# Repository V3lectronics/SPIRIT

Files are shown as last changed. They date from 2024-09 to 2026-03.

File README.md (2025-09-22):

<p align="center">
    
</p>





Open source smartphone, from available components. Prioritizing user experience, performance, control, repairability, innovation and privacy.
Contribution and feedback are very welcome! **[Contribution Guide](https://github.com/V3lectronics/SPIRIT/blob/main/CONTRIBUTING.md)**.

We are currently in the development phase, progress is documented here and on the V Electronics **[YT channel](https://www.youtube.com/@V_Electronics)**. For information about the project please refer to the **[SPIRIT wiki](https://github.com/V3lectronics/SPIRIT/wiki)**.

> [!IMPORTANT]  
> Watch out for fake websites and repositories!
> 
> Before making suggestions and opening new discussions, search the **[issue list](https://github.com/V3lectronics/SPIRIT/issues)**!

# Quick links
1. **[Technical specifications](https://github.com/V3lectronics/SPIRIT/wiki/Overview-technical-specs)**
2. **[Hardware and electronics](https://github.com/V3lectronics/SPIRIT/wiki/Hardware-and-electronics)**
3. **[Software and operating System](https://github.com/V3lectronics/SPIRIT/wiki/Operating-system)**
4. **[SPIRIT wiki](https://github.com/V3lectronics/SPIRIT/wiki)**
5. **[Community](https://github.com/V3lectronics/SPIRIT/wiki/Community)**
6. **[Contribution guide](https://github.com/V3lectronics/SPIRIT/blob/main/CONTRIBUTING.md)**
7. **[Parts list](https://github.com/V3lectronics/SPIRIT/wiki/Parts-list)** _Coming soon!!!_
8. **[Cost](https://github.com/V3lectronics/SPIRIT/wiki/Cost)** _Coming soon!!!_
9. **[Ethical and environmental concerns](https://github.com/V3lectronics/SPIRIT/wiki/Ethical-and-environmental-concerns)**
10. **[Compliance and legality](https://github.com/V3lectronics/SPIRIT/wiki/Compliance-and-legality)**
11. **[DIY build guide](https://github.com/V3lectronics/SPIRIT/wiki/DIY-build-guide)** _Coming soon!!!_
12. **[Resources](https://github.com/barbarjan/SPIRIT#resources)**

# Roadmap

### **Chassis**  
[Public Onshape project](https://cad.onshape.com/documents/4e52c2512b67af09635f94b3/w/56ef775ef64c6c9cfce93a1f/e/4e6df7991d5269c6c76f6984) → Onshape 3D model *(in progress)* → 3D printable chassis → CNC chassis

### **Electronic systems**  
Select critical components → Footprints, symbols, 3D models → Power system *(in progress)* → Audio → GPS & GSM → LCD → Camera → Vibration & flashlight → Fingerprint scanner

### **Integration**
Integrate systems into one motherboard or modular setup.

### **OS**
Documented separately, see [OS article](https://github.com/V3lectronics/SPIRIT/wiki/Operating-system).

# Early screenshots
<small> (click to expand) </small>

<table>
  <tr>
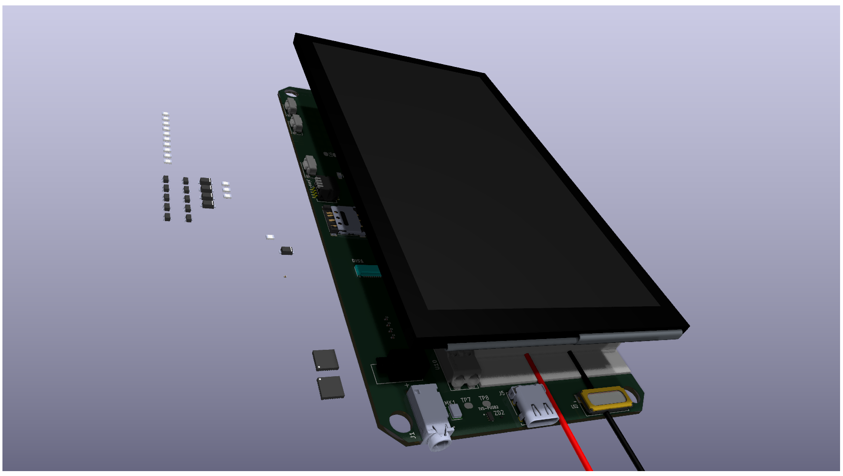
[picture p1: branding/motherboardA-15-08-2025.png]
motherboard PCB image
    <td></td>
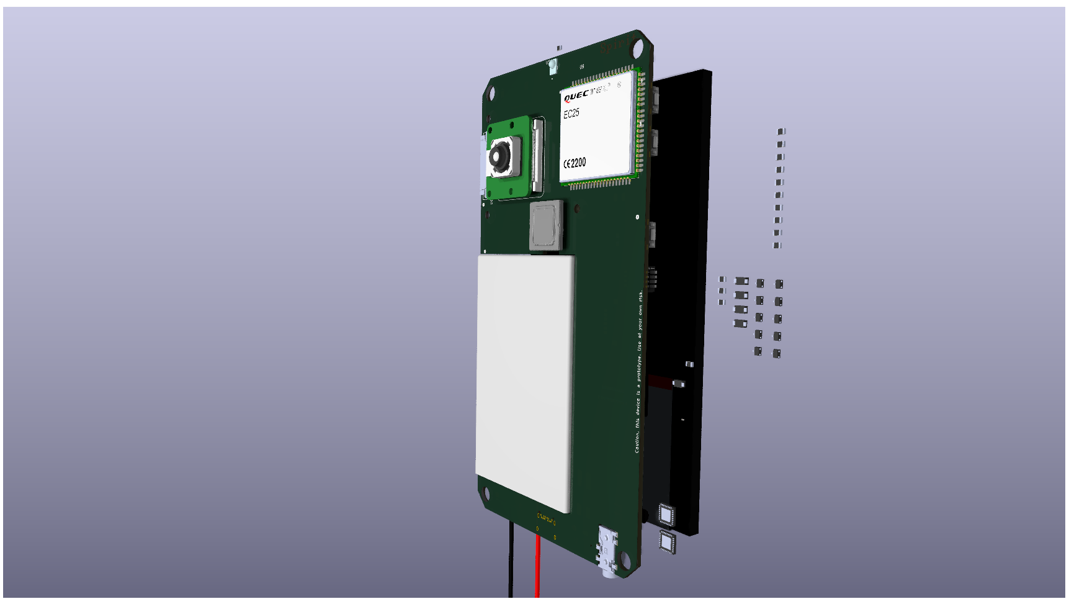
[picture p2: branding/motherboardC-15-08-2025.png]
motherboard PCB image
    <td></td>
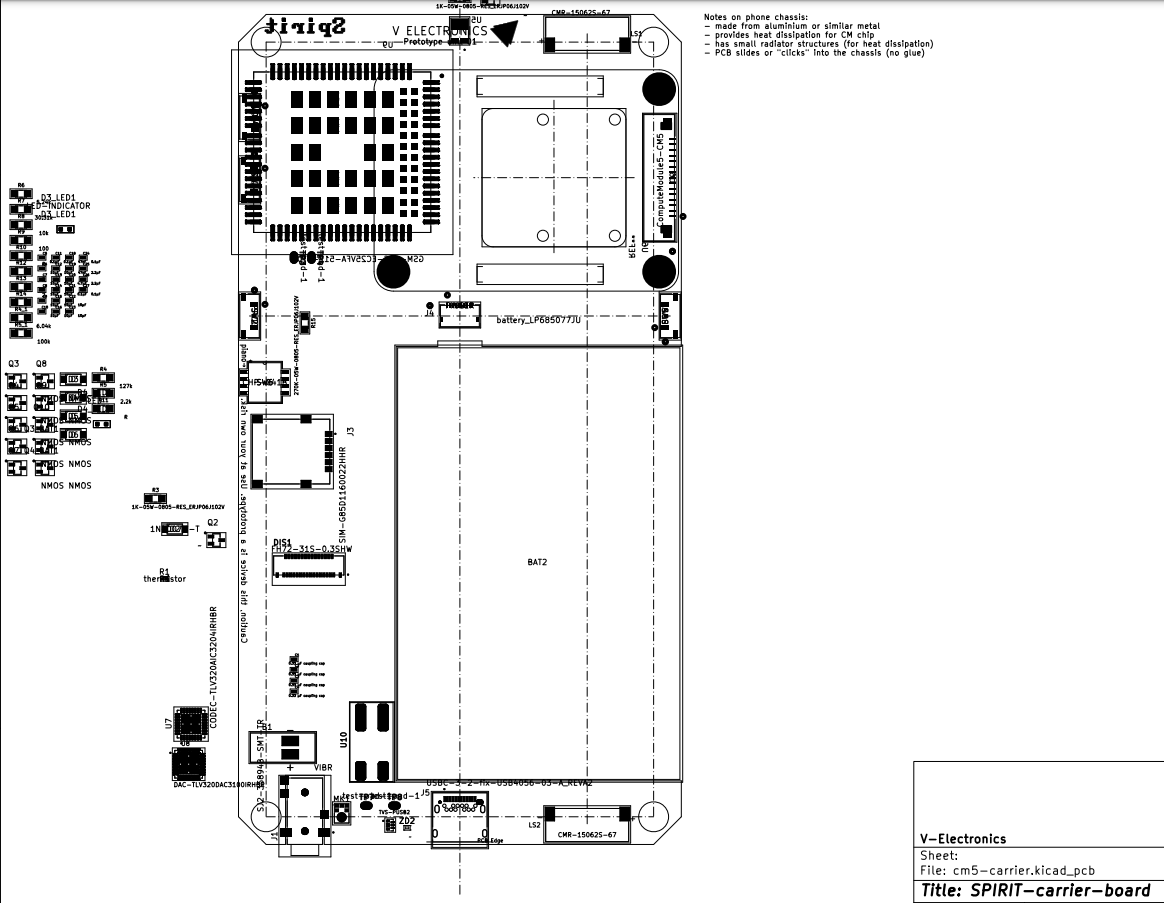
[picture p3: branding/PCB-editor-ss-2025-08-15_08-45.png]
    <td></td>
  </tr>
</table>

# Resources
- [SPIRIT wiki](https://github.com/V3lectronics/SPIRIT/wiki)
- [Rpi CM5 datasheet](https://datasheets.raspberrypi.com/cm5/cm5-datasheet.pdf)
- [Rpi CM4 datasheet](https://datasheets.raspberrypi.com/cm4/cm4-datasheet.pdf)
- [Rpi CM5 and CM 4 useful interactive pinout](https://atctwo.net/projects/pinout/index.html)

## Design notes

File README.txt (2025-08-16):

<p align="center">
    
</p>




Open source smartphone, from available components. Prioritizing user experience, performance, control, repairability, innovation and privacy.
Contribution and feedback are very welcome! [Contribution Guide](https://github.com/V3lectronics/SPIRIT/blob/main/CONTRIBUTING.md).

We are currently in the development phase, progress is documented here and on the V Electronics [YT channel](https://www.youtube.com/@V_Electronics). For information about the project please refer to the **[SPIRIT wiki](https://github.com/V3lectronics/SPIRIT/wiki)**.

# Quick links
1. **[Technical specifications](https://github.com/V3lectronics/SPIRIT/wiki/Overview-technical-specs)**
2. **[Hardware and electronics](https://github.com/V3lectronics/SPIRIT/wiki/Hardware-and-electronics)**
3. **[Software and operating System](https://github.com/V3lectronics/SPIRIT/wiki/Operating-system)**
4. **[SPIRIT wiki](https://github.com/V3lectronics/SPIRIT/wiki)**
5. **[Community](https://github.com/V3lectronics/SPIRIT/wiki/Community)**
6. **[Contribution guide](https://github.com/V3lectronics/SPIRIT/blob/main/CONTRIBUTING.md)**
7. **[Parts list](https://github.com/V3lectronics/SPIRIT/wiki/Parts-list)**
8. **[Cost](https://github.com/V3lectronics/SPIRIT/wiki/Cost)**
9. **[Ethical and environmental concerns](https://github.com/V3lectronics/SPIRIT/wiki/Ethical-and-environmental-concerns)**
10. **[Compliance and legality](https://github.com/V3lectronics/SPIRIT/wiki/Compliance-and-legality)**
11. **[DIY build guide](https://github.com/V3lectronics/SPIRIT/wiki/DIY-build-guide)** _Coming soon!!!_
12. **[Resources](https://github.com/barbarjan/SPIRIT#resources)**

# Progress



# Early screenshots
<small> (click to expand) </small>

<table>
  <tr>
    <td>motherboard PCB image</td>
    <td>motherboard PCB image</td>
    <td>motherboard PCB image</td>
  </tr>
</table>

# Resources
- [SPIRIT wiki](https://github.com/V3lectronics/SPIRIT/wiki)
- [Rpi CM5 datasheet](https://datasheets.raspberrypi.com/cm5/cm5-datasheet.pdf)
- [Rpi CM4 datasheet](https://datasheets.raspberrypi.com/cm4/cm4-datasheet.pdf)
- [Rpi CM5 and CM 4 useful interactive pinout](https://atctwo.net/projects/pinout/index.html)

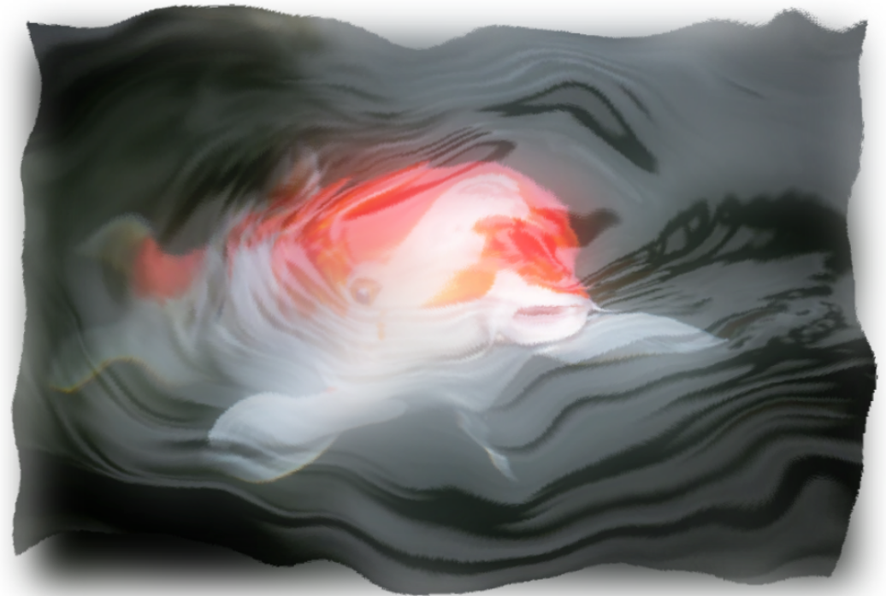
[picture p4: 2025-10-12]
branding/victoria-fish.png

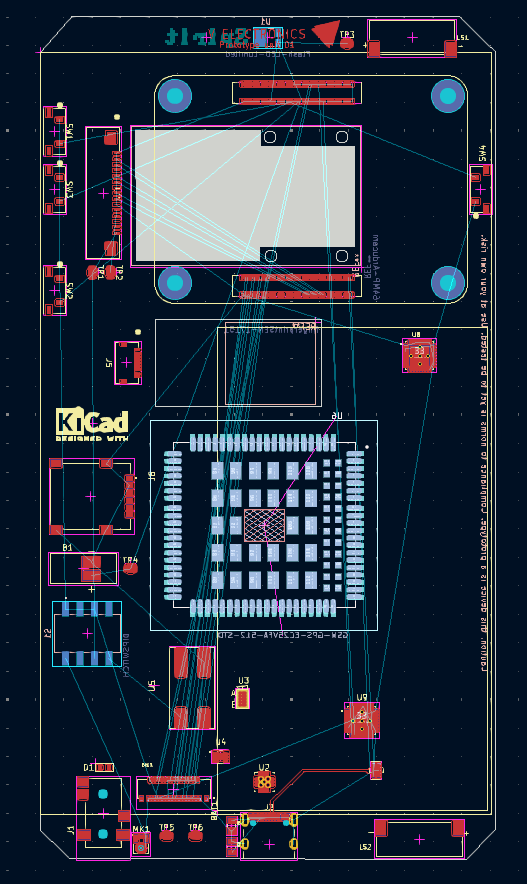
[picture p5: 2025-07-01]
branding/pcblayout26-12-2024.png

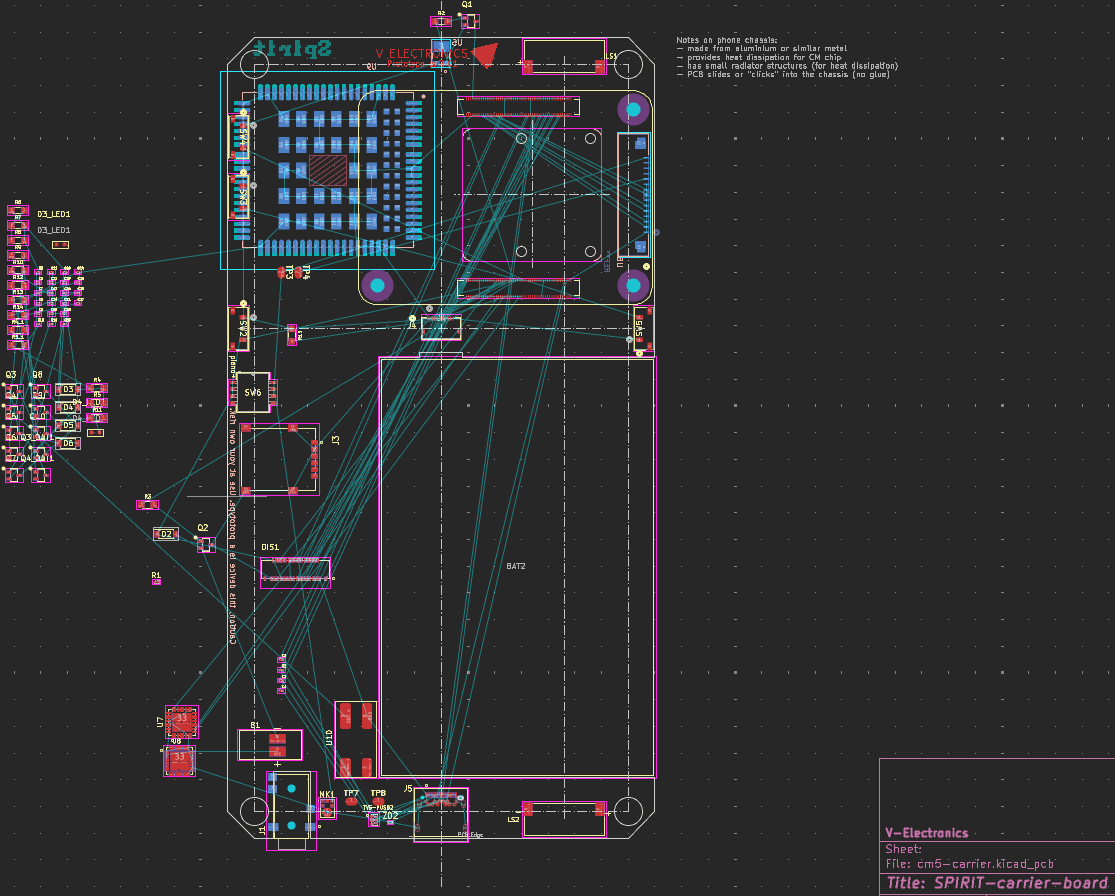
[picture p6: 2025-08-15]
branding/PCB-editor-ss-2025-08-15_08-57.png

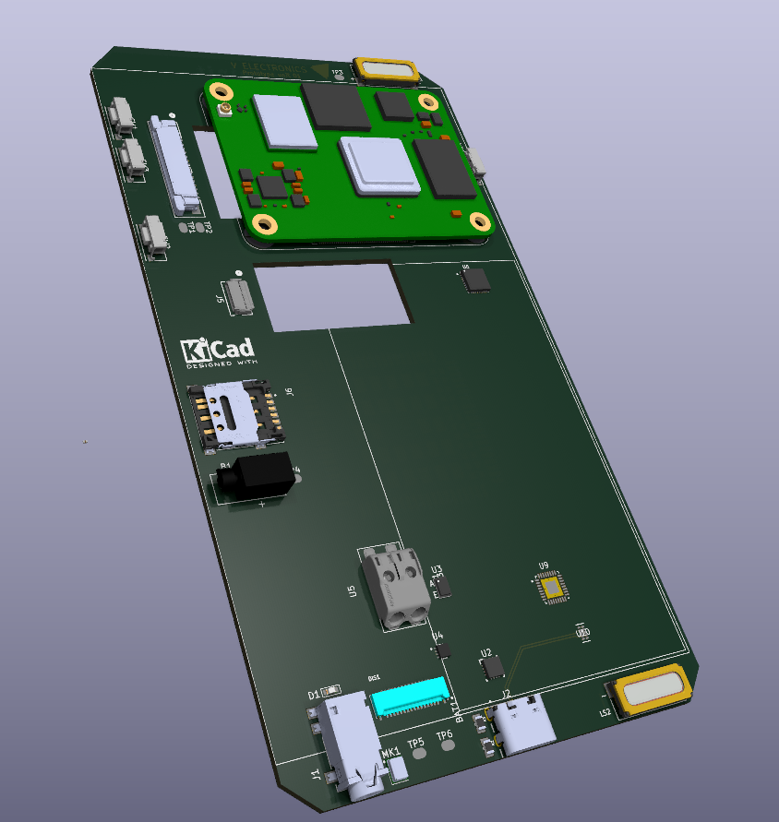
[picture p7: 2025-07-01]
branding/alt3view26-12-2024.png

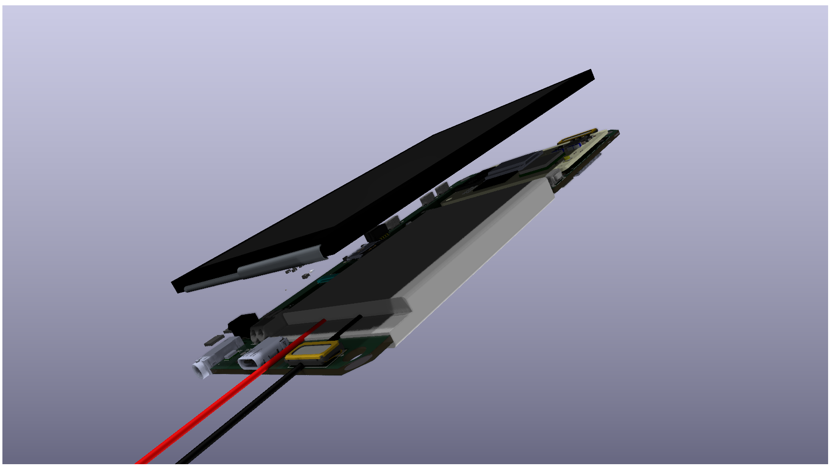
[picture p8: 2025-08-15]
branding/motherboardB-15-08-2025.png

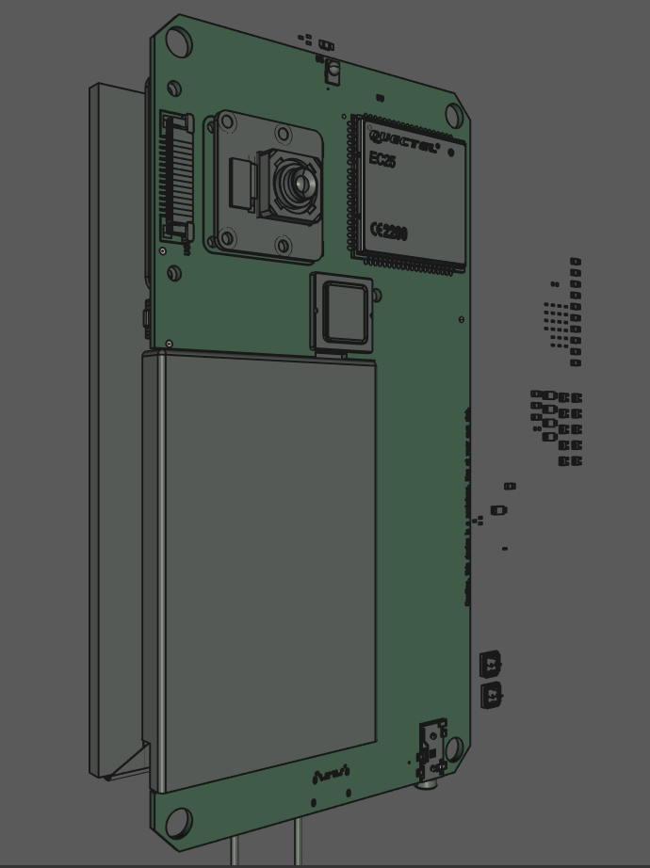
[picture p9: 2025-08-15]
branding/Freecad-ss-2025-08-15_09-00.png

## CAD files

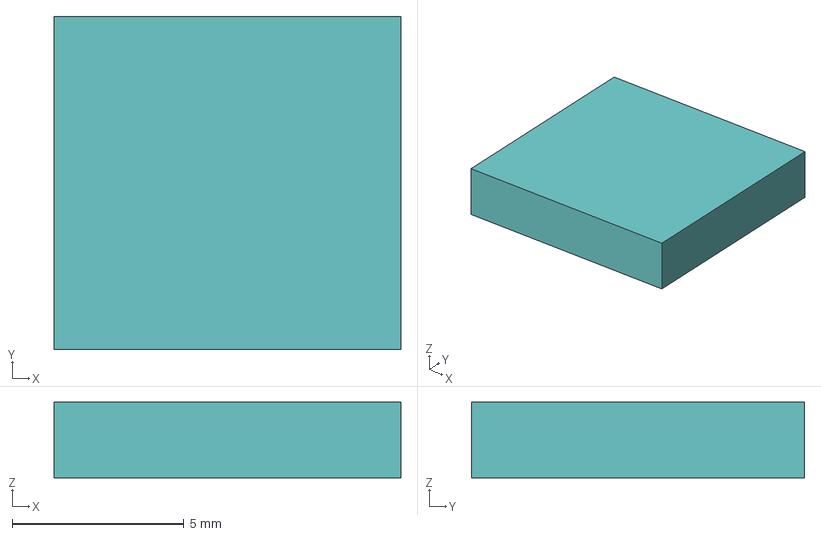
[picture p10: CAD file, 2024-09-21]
EDA-kicad/component-libs/SPIRIT-3D-models/FreeCAD-models/GPS-MODULE-YIC31009EBGG.FCStd
10.1 x 9.70 x 2.20 mm

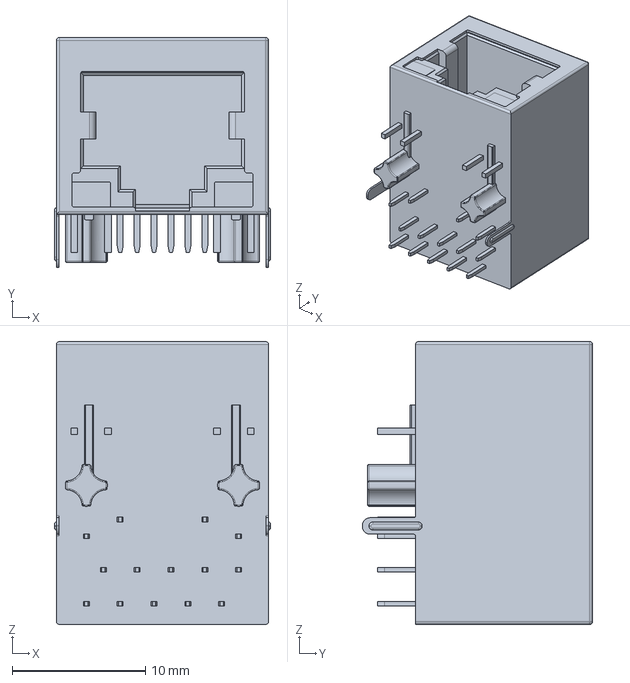
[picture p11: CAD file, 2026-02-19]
EDA-kicad/component-libs/SPIRIT-3D-models/TRJG0926HENL.stp
16.2 x 17.3 x 21.2 mm

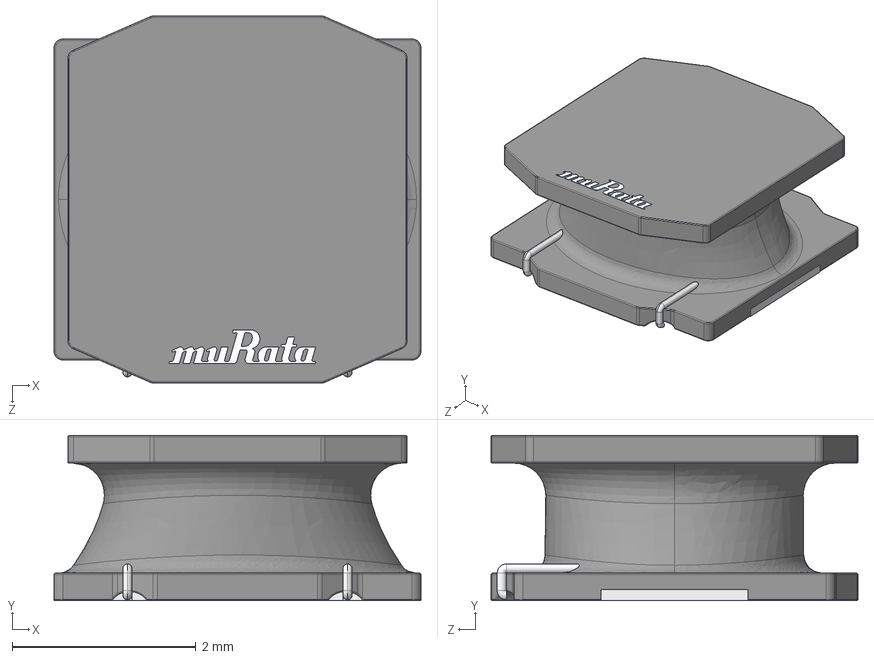
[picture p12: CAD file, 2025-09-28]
EDA-kicad/component-libs/SPIRIT-symbol-libs/3-3uH-LQH44PN3R3MPRL.step
4.00 x 1.80 x 4.00 mm
logo
terminals
terminal wire

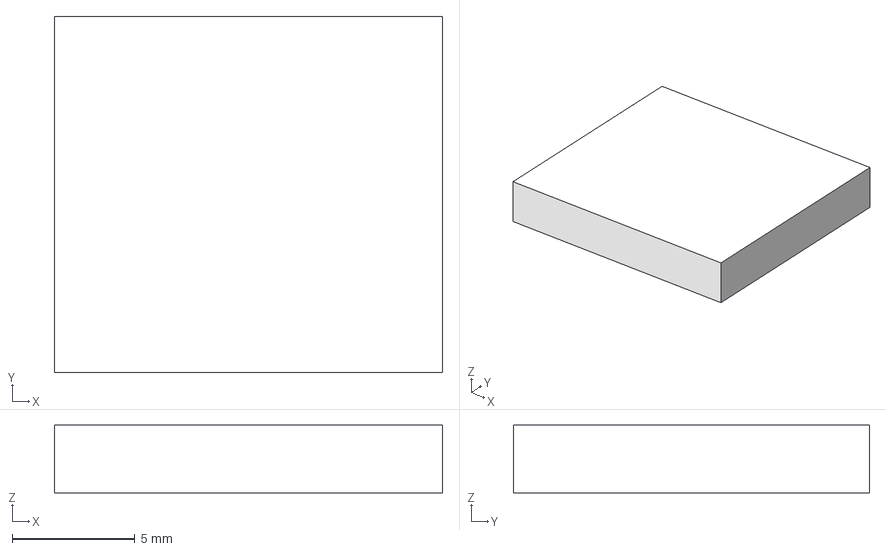
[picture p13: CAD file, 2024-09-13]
EDA-kicad/component-libs/SPIRIT-3D-models/FreeCAD-models/fingerprintSEN-17151.FCStd
15.8 x 14.5 x 2.75 mm

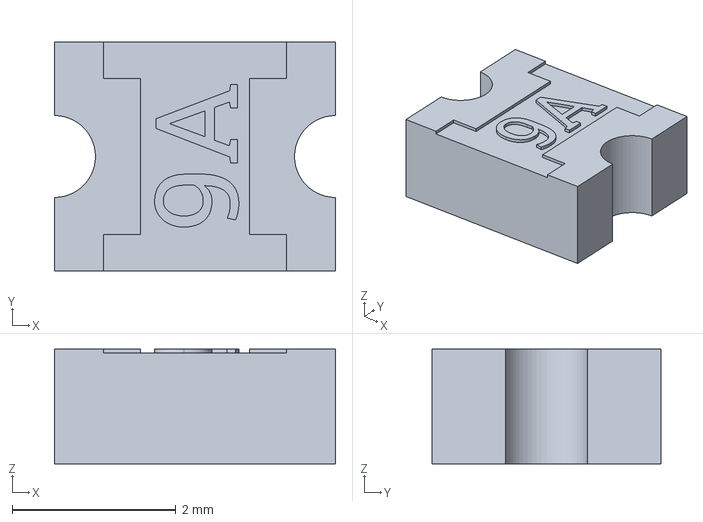
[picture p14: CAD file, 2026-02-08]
EDA-kicad/component-libs/SPIRIT-3D-models/reset-fuse-1210L900SLPR-Part.step
3.43 x 2.80 x 1.40 mm

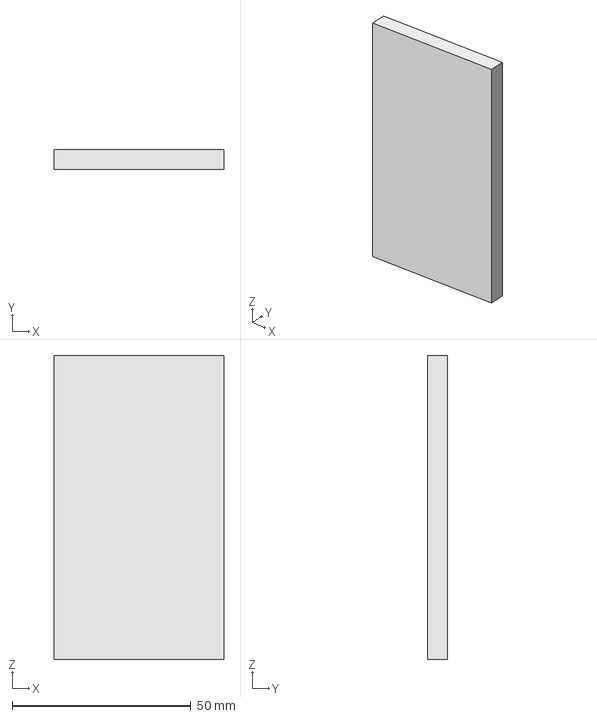
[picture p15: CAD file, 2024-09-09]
EDA-kicad/component-libs/SPIRIT-3D-models/FreeCAD-models/battery-37V2AhLP504783JU.FCStd
47.5 x 5.60 x 85.0 mm

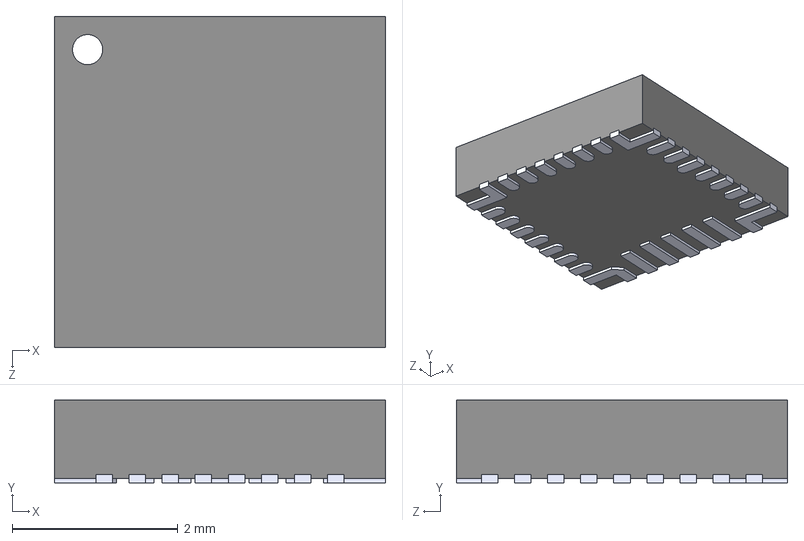
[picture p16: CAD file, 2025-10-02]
EDA-kicad/component-libs/SPIRIT-3D-models/charger-BQ25792RQMR.step
4.00 x 1.00 x 4.00 mm

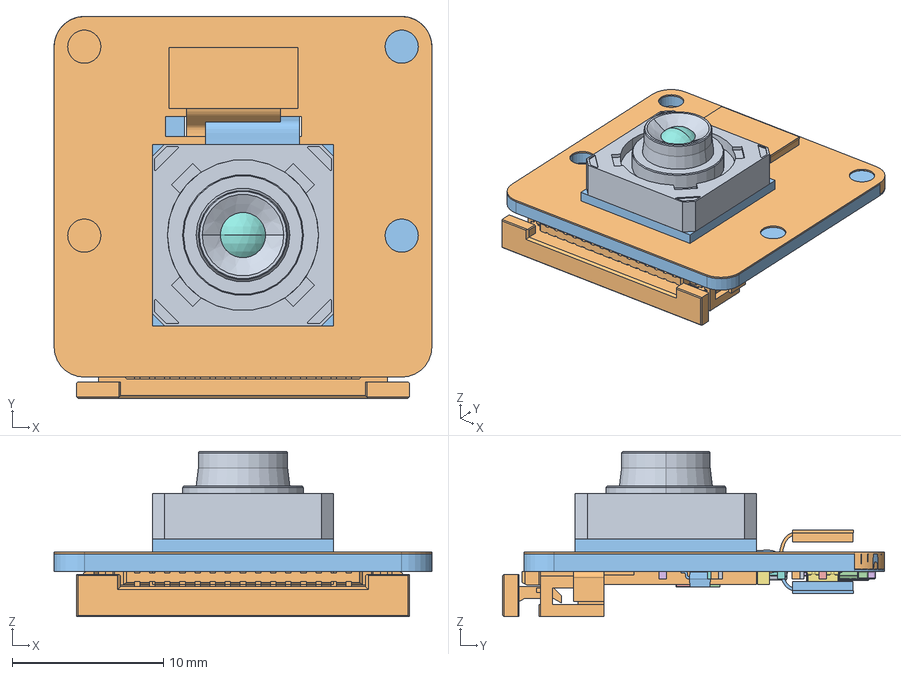
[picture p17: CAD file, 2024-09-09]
EDA-kicad/component-libs/SPIRIT-3D-models/FreeCAD-models/64MP-Arducam-colorless.FCStd
25.0 x 25.3 x 10.9 mm
B0399
B0400
B0401
B0402
B0403
B0404
B0405
B0406
B0407
B0408
B0409
B0410
B0411
B0412
B0413
B0414
B0415
B0416
B0417
B0418
B0419
B0420
B0421
B0422
B0423
B0424
B0425
B0426
B0427
B0428
B0429
B0430
B0431
B0432
B0433
B0434
B0435
B0436
B0437
B0438
B0439
B0440
B0441
B0442
B0443
B0444
B0445
B0446
B0447
B0448
B0449
B0450
B0451
B0452
B0453
B0454
B0455
B0456
B0457
B0458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

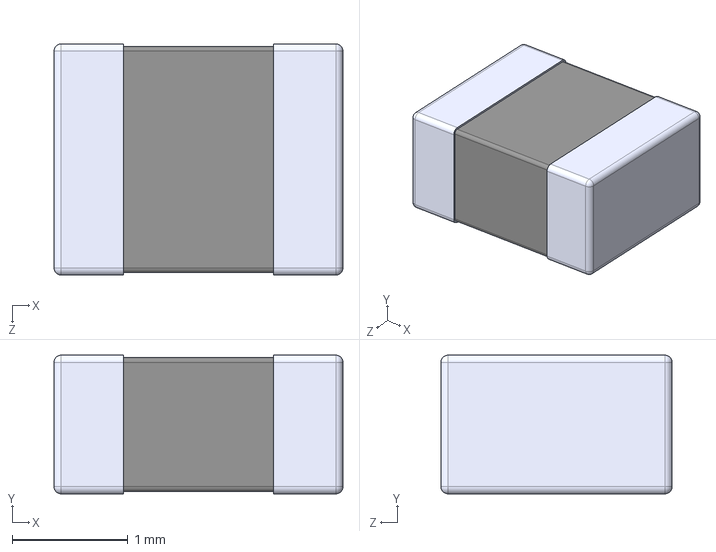
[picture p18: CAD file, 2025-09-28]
EDA-kicad/component-libs/SPIRIT-3D-models/2-2uH-inductor-DFE252012P-2R2M_P2.step
2.50 x 1.20 x 2.00 mm

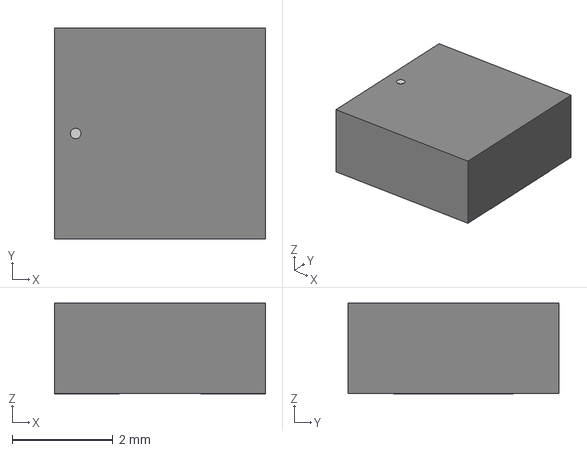
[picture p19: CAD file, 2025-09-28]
EDA-kicad/component-libs/SPIRIT-3D-models/6-8uH-inductor-LQH44PN6R8MPRLIND_LQH44PN_PR_MUR.step
4.19 x 4.19 x 1.81 mm

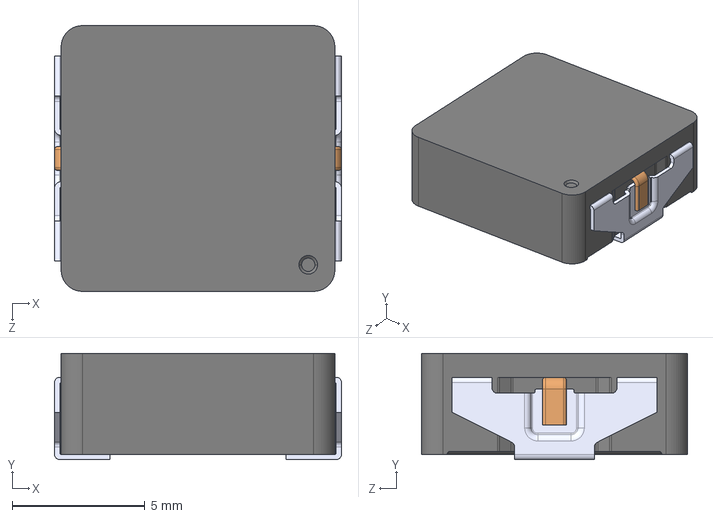
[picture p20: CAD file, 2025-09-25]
EDA-kicad/component-libs/SPIRIT-3D-models/2-2uh-inductorETQP4M2R2KVC.step
10.8 x 4.00 x 10.0 mm

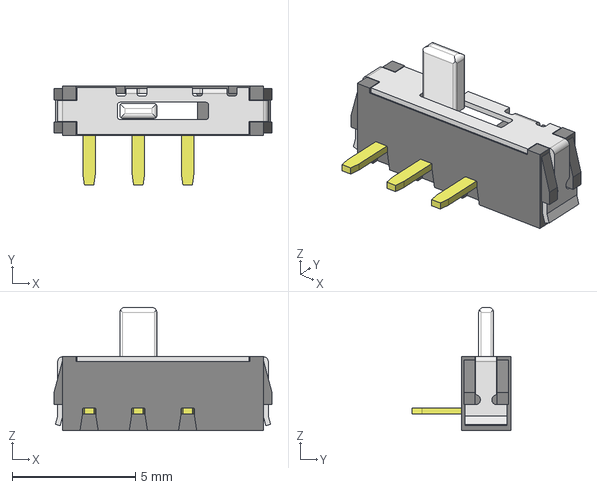
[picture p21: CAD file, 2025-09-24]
EDA-kicad/component-libs/SPIRIT-3D-models/privacy-switch-CSS-1210MC.stp
8.85 x 4.00 x 5.00 mm
CSS-1210MC-b
CSS-1210MC-s

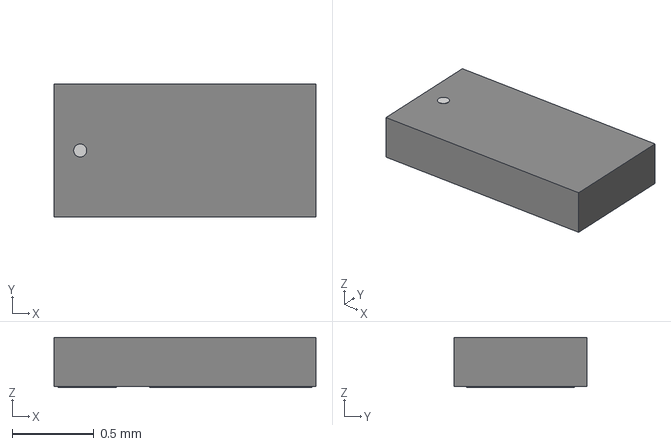
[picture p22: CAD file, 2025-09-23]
EDA-kicad/component-libs/SPIRIT-3D-models/0603-schottky-CR_DSN2_152AB-C_OSI.step
1.60 x 0.812 x 0.307 mm

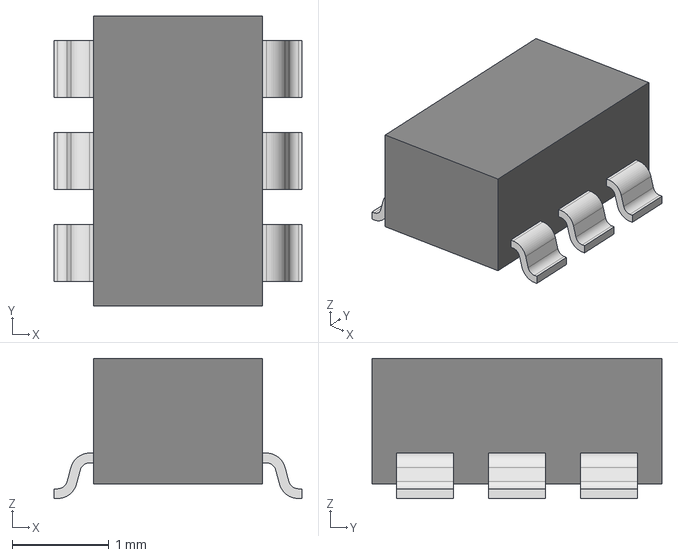
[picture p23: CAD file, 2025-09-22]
EDA-kicad/component-libs/SPIRIT-3D-models/SOT23-6_DIO.step
2.56 x 3.00 x 1.45 mm

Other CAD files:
EDA-kicad/component-libs/SPIRIT-3D-models/CC0805MKX5R5BB476-capacitor.STEP
EDA-kicad/component-libs/SPIRIT-3D-models/MP3429GL.step
EDA-kicad/component-libs/SPIRIT-3D-models/BSC0902NSIATMA1-PG-TDSON-8-6.step
EDA-kicad/component-libs/SPIRIT-3D-models/0603-capacitor.step
EDA-kicad/component-libs/SPIRIT-3D-models/0603-resistor.step
EDA-kicad/component-libs/SPIRIT-3D-models/10-FPC-unused.stp
EDA-kicad/component-libs/SPIRIT-3D-models/10-FPC.stp
EDA-kicad/component-libs/SPIRIT-3D-models/100K-0805-resistor-ERA6AEB104V.step
EDA-kicad/component-libs/SPIRIT-3D-models/1K-05W-0805-RES_ERJP06J102V.step
EDA-kicad/component-libs/SPIRIT-3D-models/35mmJACK-Same_Sky_SJ2-35894B-SMT-TR.step
EDA-kicad/component-libs/SPIRIT-3D-models/5-1KOhm-SMD-1perc-0125W-RTE0016C_NV.step
EDA-kicad/component-libs/SPIRIT-3D-models/Arducam16MPCamera.STEP
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

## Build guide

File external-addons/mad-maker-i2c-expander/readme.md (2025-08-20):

to do: provide an explanation and instructions on how to use this addon

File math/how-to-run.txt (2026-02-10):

The calculations are carried out in Octave, a free and open source program often described as a Matlab alternative. It is possible to run them in Matlab as well because the synthax is mostly compatible.

Octave website:
https://octave.org/

Octave download:
https://octave.org/download

TERMINAL
To run a file for example "test.m", simply execute the command:

$ octave test.m

This should start executing commands from the file line by line.

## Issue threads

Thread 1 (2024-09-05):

Can't add micro HDMI for debugging purposes (in case USB doesn't work)

V3lectronics, 2024-09-05:

Closed 2024-09-07.

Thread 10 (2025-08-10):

Add battery 3D .step model

V3lectronics, 2025-08-10:
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

datasheet with dimensions:
https://www.jauch.com/downloadfile/649e9f79226030849a0f5aea667759677/matd_251919_20230626_lp685077jupcm2_wires_70mm.pdf

MavLeague, 2025-08-12:
I could quickly make a model, if no one is already at it. But the dimensions are pretty plain, so except the main dimensions, I think I have to guess with like the wire placement.

boelle, 2025-08-13:
i think we can close this one as the model has been added
@V3lectronics

Closed 2025-08-13.

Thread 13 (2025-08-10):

Chassis: CAD Model, technical Drawings, Manufacturing Formats

MavLeague, 2025-08-10:
Todo:
- [ ] CAD Model
- [ ] technical Drawings for Product Qualifications
- [ ] Tool paths etc. for CNC machining

CAD Software: Onshape
- Public Project
- Browser based
everyone can follow the design process and see where I'm at

boelle, 2025-08-10:
Q: can others also edit or suggest edits ? i plan to invest in the hardware at some point if someone will help me get latest android working on it

my aim was to replace my old samsung with something i can fix myself if things break or wear out

MavLeague, 2025-08-10:
Yes, that's the plan. Onshape offers a version-history and is also made for collaboration with others. So I hope that it has the most benefit for this project. Also I am to be honest not really familiar with the workflow in fusion. I'm not sure if it offers the same benefits Onshape does.

boelle, 2025-08-10:
it does not have versio history, but you can give access to other people so they can work on the same model

a yes it does have some kind of version history in that each time you save the document gets a higher version number and you can revert to a version in the past if you F'up things

MavLeague, 2025-08-10:
Okay, but the workflow isn't like the cad workflow I am used to. Also I am not sure if public Projects are easily possible. So I think it's best to stick to Onshape for now.

But don't worry, suggestions are of course welcome!

MavLeague, 2025-08-13:
```mermaid
flowchart LR
    A[General 3D model<br/>based on PCB] --> B[Derive]

    B --> C[Optimize for 3D printing]
    C --> D[Slice]

    B --> E[Optimize for CNC Milling]
    E --> F[Technical Drawing]
    F --> G[Write CNC machining program]

MavLeague, 2025-08-13:
I've created a little Roadmap to show what my Plan is:

```mermaid
flowchart LR
    A[General 3D model<br/>based on PCB] --> B[Derive]

    B --> C[Optimize for 3D printing]
    C --> D[Slice]

    B --> E[Optimize for CNC Milling]
    E --> F[Technical Drawing]
    E --> G[Write CNC machining program]

MavLeague, 2025-08-16:
> Can anyone contribute to this?
>

It's a bit more complicated, but my goal is to explain that in the wiki. In a nutshell, we don't use GitHub but Onshape for creating the chassis so we have to approach it differently.

V3lectronics, 2025-08-20:
cm5 has been put to the back for better thermals:

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

koishi-514-shutdown, 2025-08-21:
希望外壳的摄像头不要占用背板大量面积，就像以前的手机一样简洁像iPhone6一样，并且可以在桌面上放平。
关于cm5的散热问题，我觉得可以在外壳相应位置提供类似铜或铝垫片来提供被动散热
希望可以有对应的3d打印手机壳模型
建议手机外壳设计的时候考虑电池的拆卸方便，设计一个结构可靠简单的外壳

V3lectronics, 2025-08-22:
button clearance fixed!

MavLeague, 2025-08-26:
There's now a wiki entry according to this issue.

This is a snippet of that:

## Designing Process

### CAD Software

You probably wonder where and how we create the model. We use Onshape as our CAD Program of choice because it makes collaboration really easy.

### View Progress

To see where we're at you can access the [Public Project at Onshape.](https://cad.onshape.com/documents/4e52c2512b67af09635f94b3/w/56ef775ef64c6c9cfce93a1f/e/4e6df7991d5269c6c76f6984)

To view it you **need** an Onshape Account (but the free plan is enough).

### Contribute
[_coming soon..._]

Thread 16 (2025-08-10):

Suggestion/idea... different sim card trays

boelle, 2025-08-10:
once we have a working prototype, why not have different sim card trays for the different sizes?

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

i would say skip the standard and concentrate on nano, micro and mini in that order

V3lectronics, 2025-08-15:
A simple adapter can be used, that's a standard solution:

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

boelle, 2025-08-15:
the tray just have to fit the largest one :-D

V3lectronics, 2025-08-15:
I'll close this for now

Closed 2025-08-15.

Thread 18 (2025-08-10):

GSM/GPS section (EC25 GSM/GPS, SIM holder)

V3lectronics, 2025-08-10:
We need someone to deal with the GSM/GPS schematic in KiCad

Main chip: https://www.digikey.pl/en/products/detail/quectel/EC25VFA-512-STD/13278151

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

BigBOSSJake, 2025-08-13:
Witch form factor do you like , I have a few Global options,and you want a phone network or just GPS?

BigBOSSJake, 2025-08-14:
The one that you have found is not vary global or easy to remove , a M.2 one is better for a lot of resons.

boelle, 2025-08-14:
hmm... would it not be the smartest to have wifi and gps seperate so you can update only one if say we get wifi 8 but that we still only have LTE 5G, no reason to update the GSM part then

V3lectronics, 2025-08-15:
Are we settling on eg25 as an upgrade to ec25? Maybe there are other suggestions?

BigBOSSJake, 2025-09-17:
Are we done ?

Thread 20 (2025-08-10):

POWER section (IN PROGRESS)

V3lectronics, 2025-08-10:
Help needed with implementing the power section schematic.

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

DansDesigns, 2025-08-29:
what are your main power requirements? are you running 5v into the CM? do you need 3v3 and 1v8 anywhere on the board?

I decided to use an off-the-shelf power converter that takes a native 1S lipo and converts it to 5v 3A, from there i am using 3v3 LDOs for local power where needed and to the CM for main 5v power...

V3lectronics, 2025-09-02:
Evaluation module from TI with the BQ25798:
https://www.ti.com/lit/ug/sluucb5e/sluucb5e.pdf?ts=1756794755662

Very useful, includes schematics and payout!!!

MrPouette, 2025-09-17:
We where looking to blink the R1202A regulator to modulate the Backlight brightness in the Youtube Live. But that would modulate the whole rail.
If it's only for the lcd, it seem to be a good solution to use less part but that would require to change the R1202A for a R1202D. Otherwise, we will modulate the output by the Output Capacitor Discharge Fet trough the CE pin(I think please take another look to the block diagram in datasheet).

Are we trying to conceive a 22V power rail for multiple part or only for the screen(RK055AHD091) ?

V3lectronics, 2025-09-19:
> Are we trying to conceive a 22V power rail for multiple part or only for the screen(RK055AHD091) ?
The 22V rail is only for the screen

as for the A/D version I think you're right but I'm not 100% sure.

V3lectronics, 2025-10-02:
Implemented, double check needed

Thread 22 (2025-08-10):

possible solutions

DansDesigns, 2025-08-10:
I have been working on my own version of an open-source modular smartphone based around off-the-shelf components: CM4 SBC's, Waveshare HDMI touchscreens and an m.2 4g worldwide radio module..

I have worked through a few of the problems I see you are also having, I would love to help where I can..

EasyEDA Pro (is still free but just more features) is able to produce 3d models for all* components and can export the populated pcb + silkscreen to a .obj

I have 3d models of the (3mf format to preserve colouring) RPi CM4, RPi Zero 2W and a blank CM4 -> Zero 2w adaptor plate, sd card, sim card and a M.2 SIM7600-G-H module on my OSM-Phone github (uploading shortly after this message)..

if you have a windows pc (or can run windows 10/11 in a VM), microsoft 3D Builder is an excellent program for combining all the 3d files (pcb exports & the Pi models) together along with easy case construction.. the entire thing can be viewed in X-ray or parts can be painted with a transparent colour..

have you considered FCC, CE or UKCA certification for wireless devices? using pre-certified modules can save ALOT of cost - if selling as a kit the user assembles themselves, one can avoid the need for extra certification but there MUST be a warning/disclaimer on the site + product packaging..

have you considered 3d printing or injection moulding for the casing?

boelle, 2025-08-11:
we use kicad so far and it can also export/import to step format and we do have colors

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

and yes i suggested the kit model to avoid certification

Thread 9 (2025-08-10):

Find lighter cm5 .step model and replace the current one

V3lectronics, 2025-08-10:
The current one is causing very slow rendering in the KiCad 3D view

boelle, 2025-08-13:
i added this one so we can also close
@V3lectronics

Closed 2025-08-13.

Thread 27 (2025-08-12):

Breakout board connector!

Sankie005, 2025-08-12:
Hi! I too have fallen down this rabbit hole before and was ultimately shot down because i was unable to find the right display but I was wondering if you planned on integrating an fpc or similar breakout board connector for the unused GPIO pins for creating a breakout board and adding the remaining features (flipper zero etc), this way only a smaller part of the board needs to be remanufactured as part of iteration and development can be made simpler [example connector ](https://www.digikey.com/en/products/detail/molex/5051105091/5254664) It would also mean that the phone is more modular (for example some users might value an air quality sensor over a flipper zero module, a solar power module etc) This would also have the added benifit of being more environmentally friendly as future versions of the phone could reuse old breakout boards with the sensor packages and vice versa! This is very ambitious and i'd be happy to contribute if it was made a little easier to develop! Also PS please have the next iteration use something like this [NX5 module](https://radxa.com/products/medge/nx5)!! Significantly more efficient!

00madmaker00, 2025-08-21:
We do have an addon that will allow users to access additional i2c as well as the GPIO. I believe we are documenting this in another issue "Addons/external modules #49"

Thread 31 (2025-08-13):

Touchscreen

V3lectronics, 2025-08-13:
Concerning the discussion about upgrading from https://www.digikey.com/en/products/detail/nxp-usa-inc/RK055HDMIPI4MA0/16274141

to

https://focuslcds.com/product/e55rb-i-mw400-c/

### Low stock

I sent an email to FocusLCDs asking if they plan to increase their their stock (5 units at the time of writing). Here is their response:

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

I.e. we don't know if the stock will be increased and 5 units is just too little to bet on. The 5 available are probably just samples for companies that plan to place big orders.

### Cost

The prices are similar, difficult to judge because idk if their website price includes VAT. Overall the FocusLCDs is slightly more expensive.

### Logistics

The bigger issue is with logistics: all other components are available from Digikey so they can be sent in one package (maybe except the battery which cannot be sent by air).

Additionally, Digikey provides free shipment for large orders (components for a single SPIRIT are expensive enough to get free shipping from Digikey).

Tldr: it makes sense cost-wise to order all components from one distributor if possible!

### Decision

For now we stick to https://www.digikey.com/en/products/detail/nxp-usa-inc/RK055HDMIPI4MA0/16274141

(If SPIRIT were a mass produced device I would take the other option)

V3lectronics, 2025-08-14:
https://www.waveshare.com/5dp-caplcd.htm

has been proposed as an alternative to

https://www.digikey.pl/en/products/detail/nxp-usa-inc/RK055HDMIPI4MA0/16274141

### 1 Too much IO

All of the IO on the carrier PCB of this screen takes too much space compared to just having one MIPI interface.

### 2 Not available on Digikey

For easier logistics and free shipping it is much more efficient to order all components from one distributor.

### 3 Lower specs

The resolution AND screen size are smaller

Engineer162, 2025-08-16:
I found a screen on AliExpress (the goat) that seem to be worth looking at as it has a higher resolution, is cheaper, and is made by a company with some decent reputation.

47 EURO 1080P AMOLED touch screen: https://www.aliexpress.com/item/1005004285318699.html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

Yes, I know it's from AliExpress, but the seller Wisecoco has a huge selection to choose from and for a good price. Also, we will have to get the pinout for the 40 pin FPC connector, although I'm sure the seller is willing to provide that.

Here are also links to the 2 known Wisecoco stores.

First store: https://wisecocoscreen.aliexpress.com/store/311228?spm=a2g0o.detail.0.0.5c3birfXirfXQH

Second store: https://www.aliexpress.com/store/4682114?spm=a2g0o.detail.0.0.e1019thX9thXq0

LetsPlaySimi, 2025-08-16:
I've found what seems to be the same screen but higher resolution for cheaper.

https://de.aliexpress.com/item/1005006270340420.html

I know it looks sus but the seller has good reviews, many sold items, and even if it doesn't work, AliExpress offers free returns and refunds your payment if it's broken. Also AliExpress pricing is just weird.

Engineer162, 2025-08-16:
I looked at that screen before, the only problem is that I does not have touch. Otherwise I would have linked to that one instead of the Amoled one.

V3lectronics, 2025-08-19:
> is cheaper

It's cheaper because it doesn't have the driver included !!! (almost got me XD)

also keep in mind you need to pay for shipping and the price increases with each unit, very bad for a (perhaps-one-day-massproducable device). Digikey ships for free if we order all parts from them.

@Engineer162

Engineer162, 2025-08-19:
Ah that’s just the screen mipi to hdmi converter and controller, the current screen you are using im fairly certain already uses mipi. So this screen should already function out of the box with the cm5 as long as it is correctly pin mapped, as it uses the mipi standard interface with touch over IC2 (I think). I will most likely purchase this screen and test it with my Pi 5 to make sure everything works.

@V3lectronics

Engineer162, 2025-08-20:
We don’t need that board nor that white cable, as it’s converting from the screens mipi to hdmi. Because the current design of the phone already uses mipi, we don’t need the board as you are using the same protocol as this 1080p display. Which means in theory all that is needed to adapt this screen from the old one is to change the connector type on the cm5 carrier.

Nevertheless I will be ordering the display (without the controller board) and testing it. Expect this to take at least a month, as shipping takes quite a while to Denmark.

Engineer162, 2025-08-22:
Here is the datasheet for that display

[TOP055FHDT00CTP01-5.5 OLED.pdf](https://github.com/user-attachments/files/21944957/TOP055FHDT00CTP01-5.5.OLED.pdf)

Secret-chest, 2025-09-03:
With the Waveshare I saw a problem that they have some standoffs for the large Pi that might be bad for this design.

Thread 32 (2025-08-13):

3D Model for Touchscreen

MavLeague, 2025-08-13:
For designing the chassis, I need a 3D Model of the Touchscreen we'll use.

Wich Touchscreen we'll use has been decided in issue #31

All Dimensions can be found here: https://www.nxp.com/docs/en/supporting-information/RK055AHD091-CTG.pdf (Page 14)

Requirements:
- STEP File format
- simple colorization
- unit: mm
- 2 Variants: "Component Area" on the side and bottom

c3am, 2025-08-13:
Hi, I would like to make the 3d model of the screen.
Why is it necessary though to have two versions? Don't we just need the one with the ribbon cable tucked under the screen?

c3am, 2025-08-13:
Also, how do I upload the file? github tells me that .step and .FCStd files are not supported in this messaging thing. Should I put the file into `main/mechanical/lib` for example and make a pull request?

boelle, 2025-08-14:
> Should I put the file into `main/mechanical/lib` for example and make a pull request?

EDA-kicad/component-libs/SPIRIT-3D-models

MavLeague, 2025-08-14:
> Why is it necessary though to have two versions? Don't we just need the one with the ribbon cable tucked under the screen?

Because the first version is the default how it's purchased and the second one is the one how it's mounted

MavLeague, 2025-08-14:
@c3am, could you contribute today so that I can start integrating the screen into the chassis? Alternatively, you could send me the model on Discord and add the pull request later.

Closed 2025-08-14.

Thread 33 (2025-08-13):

Sugestion for SDR/flipper0 like recorder

vertigofilip, 2025-08-13:
I remember different project for cyber deck on YouTube, and there was a small SDR used in there, that could potentially fit in this device.  The SDR is NESDR Nano 3 OTG. Potential problems might be with connecting (SDR is USB device), with cooling (it has external radiator on its enclose, or with range (it has external antenna), but I think it will work relatively easy, and it has good range, and range of frequencies it can scan.

vertigofilip, 2025-08-14:
In the parts list there was mentioned flipper0 like recorder, so I thought it was supposed to be something like this.

V3lectronics, 2025-08-20:
so I think it's best to make this a separate external addon

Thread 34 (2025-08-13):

a few errors in kicad

boelle, 2025-08-13:
@V3lectronics we have these errors when we try to update the pcb, i have to tidy up a storage room so will not get to it today, and tomorrow i have to seal up some small cracks in the wood in the same room

Warning: No net found for component DIS1 pad S1 (no pin S1 in symbol).
Warning: No net found for component J4 pad 11 (no pin 11 in symbol).
Warning: No net found for component J4 pad 12 (no pin 12 in symbol).
Warning: No net found for component SW2 pad 4 (no pin 4 in symbol).
Warning: No net found for component SW2 pad 3 (no pin 3 in symbol).
Warning: No net found for component SW3 pad 4 (no pin 4 in symbol).
Warning: No net found for component SW3 pad 3 (no pin 3 in symbol).
Warning: No net found for component SW4 pad 4 (no pin 4 in symbol).
Warning: No net found for component SW4 pad 3 (no pin 3 in symbol).
Warning: No net found for component SW5 pad 3 (no pin 3 in symbol).
Warning: No net found for component SW5 pad 4 (no pin 4 in symbol).
Warning: No net found for component U5 pad 3 (no pin 3 in symbol).
Warning: No net found for component DIS1 pad S2 (no pin S2 in symbol).
Warning: No net found for component U7 pad 38 (no pin 38 in symbol).
Warning: No net found for component U7 pad 36 (no pin 36 in symbol).
Warning: No net found for component U7 pad 37 (no pin 37 in symbol).
Warning: No net found for component U7 pad 35 (no pin 35 in symbol).
Warning: No net found for component U7 pad 34 (no pin 34 in symbol).
Warning: No net found for component U8 pad 38 (no pin 38 in symbol).
Warning: No net found for component U8 pad 35 (no pin 35 in symbol).
Warning: No net found for component U8 pad 15 (no pin 15 in symbol).
Warning: No net found for component U8 pad 37 (no pin 37 in symbol).
Warning: No net found for component U8 pad 34 (no pin 34 in symbol).
Warning: No net found for component U8 pad 4 (no pin 4 in symbol).
Warning: No net found for component U8 pad 36 (no pin 36 in symbol).
Error: Cannot add Q4 (no footprint assigned).
Error: Cannot add Q5 (no footprint assigned).
Error: Cannot add Q3_BAT1 (no footprint assigned).
Error: Cannot add Q9 (no footprint assigned).
Error: Cannot add Q3 (no footprint assigned).
Error: Cannot add D5 (no footprint assigned).
Error: Cannot add R4 (no footprint assigned).
Error: Cannot add L1 (no footprint assigned).
Error: Cannot add Q7 (no footprint assigned).
Error: Cannot add R11 (no footprint assigned).
Error: Cannot add Q6 (no footprint assigned).
Error: Cannot add Q8 (no footprint assigned).
Error: Cannot add D6 (no footprint assigned).
Error: Cannot add Q10 (no footprint assigned).
Error: Cannot add D4_LED1 (no footprint assigned).
Error: Cannot add R5 (no footprint assigned).
Error: Cannot add U11 (footprint 'BQ25792RQMR:QFN40P400X400X100-29N' not found).
Error: Cannot add D4 (no footprint assigned).
Error: Cannot add D3 (no footprint assigned).
Error: Cannot add C17 (no footprint assigned).
Error: Cannot add Q4_BAT1 (no footprint assigned).

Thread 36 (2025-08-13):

consider Postmarket OS for OS

6mat, 2025-08-13:
You mentioned exploring developing an os based on Debian. Postmarket OS is alpine Linux based.

easton57, 2025-08-13:
Had this thought after seeing the github. Looks like there's already a wiki page available for it. As long as the drivers for the screen and other peripherals are mainlined then it should be a fairly simple port. https://wiki.postmarketos.org/wiki/Raspberry_Pi_5_(raspberry-pi5)

BigBOSSJake, 2025-08-13:
I think, that any os that works on raspbarry py 5(or any cm) will work(like even Windows).

easton57, 2025-08-13:
Sweet. I can make a PR to add it to the readme.

boelle, 2025-08-14:
you can put any OS on it, its just a matter of what work you have to put in it for it to work

6mat, 2025-08-15:
Thank you, awesome.
I like the feel of the OS. Feels like Linux

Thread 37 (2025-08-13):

hotswappable battery

6mat, 2025-08-13:
May be consider a smaller internal battery and a hotswappable USB c battery. That if someone get two USB c battery module, you'll not run out of battery?
You can look into framework laptop for design ideas on modules .
Not sure if it'll be possible

boelle, 2025-08-14:
hmm... you are starting to exclude those that do not want to fart arround with an external battery

the current battery is easy to change, open up the case and change the battery. it has clamp style connector so you only need a screwdriver to open the case

V3lectronics, 2025-08-14:
> May be consider a smaller internal battery and a hotswappable USB c battery. That if someone get two USB c battery module, you'll not run out of battery? You can look into framework laptop for design ideas on modules . Not sure if it'll be possible

Hi, using a module like this would mean that there is only 1 battery option that is compatible with the device. The current screw-clamp mechanism makes it so that all batteries with 2 wire leads can be attached. Your idea makes sense but in our case it complicates the design and decreases compatibility.

To achieve the same exact functionality you can have 2 regular Li-poly bats with you and swap whenever you need. That would require a reboot though.

Closed 2025-08-14.

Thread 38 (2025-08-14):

Heatsink found!!

BigBOSSJake, 2025-08-14:
I have found some heatsinks, this is the link:  https://www.digikey.com/en/products/filter/thermal/heat-sinks/219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

boelle, 2025-08-14:
is the case not a big/good enough heatsink?

V3lectronics, 2025-08-14:
Not sure if heat sinks are needed, maybe for thermal coupling to the chassis? @MavLeague

MavLeague, 2025-08-14:
I don't think it's necessary right now. It would add unnecessary thickness to the phone.

Closed 2025-08-15.

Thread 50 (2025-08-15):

Power management problems with raspberry pi family

berkerogluu, 2025-08-15:
An idle pi 5 will consume 1W to 2W, raspberry pi is not designed for mobile usage. Some people suggested that governing cpu, undervolting etc will work but sadly it is far from reality. Software, kernel optimizations will not work. Raspberry pi has no true suspend-to-ram, hibernation support.. no proper power management system. It is designed to work plugged in. I think we should consider switching to orange pi, taking action now will save time and labor in the future. Some can argue we can switch to better boards later but I think we need an unified approach from start.
Orange Pi 5 also has mainline kernel support (I don't know if it's fully competed or reliable) and android.

6mat, 2025-08-15:
I think this is a very valid issue. With moderate usage and current battery set up, it'll be l draw like 4 to 5 W. So it'll last only like 2 to 3 hours. And that's considering only the Pi5. Adding screen and everything else, it'll probably be less than an hour for moderate usage

V3lectronics, 2025-08-16:
Very valid point raised here, however changing the CM now will really slow us down with the 1st prototype. We are considering these options as potentially better alternatives:

https://github.com/V3lectronics/SPIRIT/wiki/SoC-and-SoM-alternatives-to-CM5

(not an exhaustive list, contributions welcome)

easton57, 2025-08-16:
Long term for both CM5 and anything with Rockchip to keep in mind is kernel support and development. Raspberry Pi has the raspberry pi foundation behind it and a large community including other large companies and hobbyists while, Rockchip linux development was backed by a single guy who has since backed down due to burnout and a lack of support from Rockchip and other parties who were using his work for their own products. While short term something with a Rockchip may be better, software compatibility, stability and security may become a bigger concern than finding a workaround for the raspberry pi's poor power management. The rockchip situation may have changed though, I haven't heard anything too crazy since Joshua Riek stepped away last November.

https://www.jeffgeerling.com/blog/2024/popular-rockchip-sbc-distro-limbo-after-maintainer-burns-out

easton57, 2025-08-16:
There are of course others like Armlogic and some risc v boards are popping up as well.

easton57, 2025-08-29:
I will be working on this soon. Waiting on some hardware.

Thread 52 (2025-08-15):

Feature Request: Internal Charging Port

Minerik007, 2025-08-15:
# Why?
- People might want to install an additional battery or solar panel.
- This would allow sliding in a solar panel or other charging module easily.
- The only modification needed would be to reprint the back of the chassis.

V3lectronics, 2025-08-16:
1) So essentially, what you are suggesting is a secondary power input? @Minerik007

2) Are you suggesting to place it inside the chassis?

Minerik007, 2025-08-16:
> 1. So essentially, what you are suggesting is a secondary power input? [@Minerik007](https://github.com/Minerik007)
Yes.

> 2. Are you suggesting to place it inside the chassis?
Yes. Somewhere like here:
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
The port will likely face upward in this case, or downward depending on how much space is available. Ideally, we want to avoid having cables from solar panel or similar power input hanging outside the phone.

Closed 2025-09-01.

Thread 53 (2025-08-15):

OS Feature: Install apps in separate containers

Sam2159, 2025-08-15:
By installing apps in different containers, each one will be isolated from the others. This allows apps to access only the data in their specific environment, ensuring user privacy.

BigBOSSJake, 2025-08-15:
This is just the hardware not software stage .

Sam2159, 2025-08-25:
I'll see if it's possible to make a replica of BlendOS, but for arm. I can't find online an iso for an arm immutable linux distro, so the first thing that i'll try to do is build one based on arch (like the one used for BlendOS)

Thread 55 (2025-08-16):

Using pogo pins and small latches to easily swap between batteries.

DanR824, 2025-08-16:
You can add a smaller Battery in parallel so that no power is lost, a seamless battery swap with out interruption.
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

DansDesigns, 2025-08-17:
very interesting idea!
In theory you could put the phone to hibernate, have a super capacitor charge up to hold enough power for the hibernation state, disconnect the battery circuitry at the same time as the physical locking tabs are moved to their "unlocked" position and swap the batteries.. when the locking tabs are moved back into "locked" potision, the battery reconnects to take over, (recharges the super cap?) and the phone can be woken up by the power button (not sure your exact layout on power triggering)

DansDesigns, 2025-08-29:
i found a couple of replaceable batteries in the style you suggested (plastic case), alot of the ones available now have the small flex connector with the soft pouch unprotected...

heres the plastic case ones:
5200mah Samsung S4:
http://allbatteries.co.uk/mobile-phone-battery-pour-samsung-3-7v-5200mah-gml90425.html

3100mah Samsung Note3:
https://www.allbatteries.co.uk/mobile-phone-battery-pour-samsung-3-8v-3100mah-gml901518.html

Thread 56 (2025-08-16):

Heat from CM5

Dreiseratops1, 2025-08-16:
I think we need to have the CPU facing out the back and heat synced to a metal case.
CM5 thermal throttles at 80°C and it will be there at idle in the current orientation between the screen and GSM module.

DansDesigns, 2025-08-19:
I totally agree, there are however exceptions to every rule, JerryRigEverything shows during disassembly of the Unihertz rugged projector phone:
[https://youtu.be/TKlIZTmmmng?t=577](https://youtu.be/TKlIZTmmmng?t=577)
that a cooling fan can be surrounded by waterproofing, the fan itself may be a different story but with proper protection against water ingress the fan area can be well waterproofed..
The fans in question are generally silent fans designed for mobile applications but youre right, there will always be some noise..

I am looking into Vapour Chambers as an alternative, DigiKey has a nice selection but they are pricey - >£24 each!
[DigiKey Vapour Chambers](https://www.digikey.co.uk/en/products/filter/thermal/heat-pipes-vapor-chambers/977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)

Closed 2025-08-20.

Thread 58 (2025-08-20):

Suggestion: Watertight USB-C port

MavLeague, 2025-08-20:
Hello, so the current usb-c connector isn't watertight and also it had an old usb standard. But We've found a better usb-c port that is watertight according to [this datasheet](https://www.hirose.com/product/document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).

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

( I'd prefer the mid mount variant over the bottom mount variant, because then it is aligned with the audio jack in the chassis.)

It also already has 3d data for download so we don't need to make an extra model for that.

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

Here we can find it on digikey: https://www.digikey.de/en/products/detail/hirose-electric-co-ltd/CX90MW9-24P1/22607398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

**If you can find a better connector or have any ideas/ suggestions, please let us know.**

V3lectronics, 2025-08-21:
looking good I'll add it to kicad

V3lectronics, 2025-08-21:
added in KiCad!

Closed 2025-08-22.

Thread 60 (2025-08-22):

Idea for a built-in physical keyboard

RedstoneTrail, 2025-08-22:
I'm not sure how would be the best way to do this, but having the option to add a physical keyboard to the phone would be a nice option in my opinion.

I had 2 ideas of how to do this though because each has its own advantages and disadvantages.

||Blackberry-style|iPad-style|
|-|-|-|
|Description|The full-height screen is replaced with a half-height screen with a small keyboard below it taking up the rest of the length of the phone|The keyboard is folded behind the phone when out of use / can be removed and re-attached (maybe magnetically or using the resistance from a usb port|
|Benefits|Can be used in your hands with your thumbs|Still keeps a full size screen and there is a bigger keyboard (ideal for typing against a table)|
|Disadvantages|Smaller screen|Makes the phone thicker, needs to be on a table to use properly|

maybe an internal usb port could be exposed for this kind of thing or something like that

let me know what you think!

Secret-chest, 2025-09-03:
I'd suggest something like the formerly available PinePhone keyboard addon

DansDesigns, 2025-09-04:
theres also Clicks by Mr. Mobile on youtube

Secret-chest, 2025-09-06:
I suggest pogo pins implementing USB but in a different shape.

RedstoneTrail, 2025-09-06:
Thats not a bad idea, but i think it was found that that kind of solution could be too expensive (there was an issue discussing an expansion connector thing using a magnetic connector but that was a bit too expensive to buy the connectors). I think a proper usb 2 port might be a better solution, maybe it could be embedded in the back with a cutout/lowered section in the case for access from the back. other than if there are price issues, this does sound like a good solution

Secret-chest, 2025-09-06:
That could also work, imagine the keyboard having a hinge with an USB plug sticking out of it

gitmanbloggus, 2025-09-26:
or... some thunderbolt-like port to expose pcie

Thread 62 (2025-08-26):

Wasted Space by Vibration Motor

MavLeague, 2025-08-26:
Hi everyone!
I've found a little problem, we need to solve: The vibration motor wastes a lot of potential space inside the phone (1-2mm). This Image shows that:

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

### We need to check for the following to solve it:
- [ ] Is there another place we can put it?
- [ ] Can we move it there?
- [ ] If not, are there alternatives to this vibration motor?
- [ ] Do they have a lower profile?
- [ ] Is this change worth the effort?

### Possible space
A possible place with enough space could be the rim above and below the screen. But there are other very important parts such as the ports.

**Let me know your thoughts!**

00madmaker00, 2025-08-27:
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

After some searching I was able to find a pretty inexpensive component with a very low profile. I've included pictures and a link to the part on digikey.

Part name:
JYLRA0825Z

Part info:
Product Dimension: 8×2.5 mm
Rated Voltage (Vac RMS):1.2
Operating Voltage (Vac RMS):0.1~1.5
Rated Current MAX (mA):100
Typical Current (mA):58
Rise Time (ms) MAX *:50
Fall Time (ms) MAX *:80
Resonant Frequency(Hz):240
Steady Acceleration(@100g, Grms):0.8 G
20±2
Vibration Direction: Z-AXIS

https://www.digikey.com/en/products/detail/jie-yi-electronics-limited/JYLRA0825Z/22519426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

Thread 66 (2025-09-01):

Snap on / Slide out Keyboard

FXDSSTM, 2025-09-01:
### RND Keyboard and how to implement it with SPIRIT phone

Potential options for connectivity:
- USB
- I2C

Keyboard options:
- Slide out mechanism integrated into chassis
- Snap on attachment (pogo pins or plug in)

Options for microcontrollers:
- ATMega32U4
- ATMega8A

Koakno, 2025-09-01:
If it's snap on, wouldn't you want to use usb for hot swapping?

(Or am I mistaken?)

Secret-chest, 2025-09-03:
What does RND mean? Also I am very interested: where can such a sized keyboard be sourced? BlackBerry keyboards are too small and not sustainable to use.

FXDSSTM, 2025-09-04:
> What does RND mean? Also I am very interested: where can such a sized keyboard be sourced? BlackBerry keyboards are too small and not sustainable to use.

RND - Research & Develop. The idea is to create a custom keyboard from scratch that can either be implemented into a chassis design for those that want to have both screen and keyboard, or can be an "add on" for those that would like to take it with them without taking up any of the phone's space. Planned keyboard size would be more along the lines of the phone's length, but would also be able to go according to width if people want to slide up instead of to the side.

Closed 2025-09-17.

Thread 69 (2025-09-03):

How do you design the I/O boards?

Secret-chest, 2025-09-03:
I am quite interested as I want to learn more and possibly contribute/design an alternative project to this (whilst still hopefully collaborating). I have never done PCB design before, but what are good resources for making custom CM I/O boards?

Secret-chest, 2025-09-04:
Not the 3D, simply the rules that you have to follow when drawing the connections

DansDesigns, 2025-09-04:
thats a great idea, I too am working on an CM4 compatible adaptor for Pi Zero style SBCs for my OSM-Phone

V3lectronics, 2025-09-09:
> but what are good resources for making custom CM I/O boards?

I'd recommend these 2 things:
- https://www.youtube.com/watch?v=ge6gYIENo8Q
- get the original RPi CM5 IO board EDA files and modify it to your need.

V3lectronics, 2025-09-17:
closing as inactive

Closed 2025-09-17.

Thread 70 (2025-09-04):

Discussion: Boot, TEE, and Security Directions for SPIRIT

tym2k1, 2025-09-04:
I wanted to open a bigger-picture discussion around security mechanisms as there were some issues touching on this point (https://github.com/V3lectronics/SPIRIT/issues/47, https://github.com/V3lectronics/SPIRIT/issues/26) and what role these might (or might not) play in the SPIRIT project. Some folks are aiming for Android, some for Linux (PostmarketOS, etc.), and I think it’s worth aligning on what’s realistic for early prototypes vs. long-term goals.

This is **not** a blocker for running a minimal Linux or Android system on the RPi4/RPi5 CMs, those will run fine without TEEs or verified boot. But I figured it’s a good moment to talk about the security landscape so we know what’s possible, what’s wishful thinking and what is required for allowing it to be a daily driver.

## RPI5 potential hiccups

### Trusted Execution Environment (TEE)

A TEE allows for isolation of sensitive data like cryptographic keys and biometric information. For a true secure daily-driver it'd be a beneficial to
have as PIN/Password verification could live there similiar to [Gatekeeper](https://source.android.com/docs/security/features/authentication/gatekeeper) in Android that indeed does live within the Trusty TEE.

What’s available in theory:
- [Trusty TEE](https://source.android.com/docs/security/features/trusty) (Google's TEE)
  - [Open Source](https://android.googlesource.com/?format=HTML) (search for "trusty" repositories)
  - Designed to support Android’s security model
  - Porting Trusty to Pi 5 would be a major effort, since it was never designed
  for this hardware platform
  - To achieve a Google-certified Android would be the way to go. But without such certification many features wouldn't work. GrapheneOS to my knowledge avoids this issue by using Pixel Phones where Trusty and Titan chips are already certified so the non-certified OS can still utilize them
- OP-TEE
  - [Open-source](https://optee.readthedocs.io/en/latest/general/about.html) and developed by Linaro
  - Widely used on dev boards, academic projects and [easily integrated within Linux](https://docs.kernel.org/tee/op-tee.html)
  - Much more accessible to experiment with than Trusty
  - There is no maintained Android + OP-TEE integration tree anymore. [There used to be an integration with AOSP project](https://optee.readthedocs.io/en/latest/building/aosp/aosp.html)
  - OP-TEE hasn't been ported to RPI4/RPI5 but some work has already been done in this regard - https://github.com/OP-TEE/optee_os/pull/6854 / https://github.com/joaopeixoto13/OPTEE-RPI4

All other widely deployed TEEs (QSEE, Kinibi, MobiCore, etc.) are proprietary and vendor-specific, and realistically cannot be ported to Raspberry Pi.

### Boot

For any security-sensitive feature to be meaningful, the system needs a reliable way to ensure that the software loaded at boot is exactly what it should be. This is where measured, verified, or secure boot mechanisms come in: they provide a chain of trust from power-on to the running OS, cryptographically validating each stage.

[The Raspberry Pi 5 supports secure boot](https://github.com/raspberrypi/usbboot/blob/master/secure-boot-recovery5/README.md), which relies on signed bootloader images stored in the EEPROM and validated by the built-in Broadcom firmware. However it seems that the earliest boot stages are controlled by a closed-source GPU firmware, which limits full auditable verification but that might be considered just a minor drawback.

### Minor points

- The datasheet of the currently chosen biometry module [Fingerprint Cards AB 100018754](https://www.digikey.com/en/products/detail/fingerprint-cards-ab/100018754/11480144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) mentioned on [wiki](https://github.com/V3lectronics/SPIRIT/wiki/Hardware-and-electronics#biometric-module) specifies that the `CMD_IMAGE` command with `ARG_UPLOAD` argument can be used to upload the biometric image from reader to the host. I haven't found information in the datasheet if this can be somehow disabled/fused. This means that, if the hardware is not routed through TEE, fingerprint readings can be easily stolen from userspace which is kind of bad as you can't really re-enroll biometric data.

- Arm TrustZone on Raspberry Pi has a history of being a little finicky with secure/non-secure flag on the axi bus not being wired into the memory controller for [RPI3](https://forums.raspberrypi.com/viewtopic.php?t=215868), [RPI4](https://forums.raspberrypi.com/viewtopic.php?t=311331) and from my understanding on [RPI5](https://github.com/OP-TEE/optee_os/pull/6854#issue-2311622330) as well. This means that only software protection could be achieved and a compromised kernel could leak data. To achieve the secure/non-secure world isolation a static partioning hypervisor could be used like [Bao](https://github.com/bao-project/bao-hypervisor) which solved this exact issue for RPI4 and could be ported to RPI5.

- There seems to be [some talks about EU regulating hardware/app/OS verification for banking transfers](https://x.com/GrapheneOS/status/1963035841124794587) adding some hurdle for potential daily-driving SPIRIT but I couldn't find source for these claims. If the project were to be verified to support such banking uses I'm assuming it'd require the above hardening functionalities.

## Future prospects

- GrapheneOS project recently made a statement about [Google Pixel locking down support for alternate OS's](https://grapheneos.social/@GrapheneOS/115102594309778277) and it seems they might be interested in an alternative hardware for the project but it would have to support critical security features. As of now it looks that running "secure" Android would require a lot of work.

- Despite locking down alternative OS for Pixel Google has been contributing to the [OpenTitan](https://opentitan.org/) project which in short aims create an Open Source Silicon Root of Trust which serves a similiar purpose to the Google Titan M/M2 chips found in Pixel Phones. If this would to be integrated into the SPIRIT phone it could harden the security. It's also a cool research perspective as OpenTitan is currently in development phase and the SPIRIT could be a great target for it. It's also [on the radar of GrapheneOS team](https://discuss.grapheneos.org/d/12153-does-grapheneos-control-the-tee-environment/8)

## Closing thougts

I’m tossing these ideas out to get the conversation rolling. If I got something wrong just call me out (probably won’t be the last time 😅)
All of this also poses SPIRIT as a cool cybersecurity research target. Really curious to hear what others think and see the project grow <3

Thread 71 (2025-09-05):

Why do we still have the EC25 in the Schematic editor?

BigBOSSJake, 2025-09-05:
Why do we stil have the EC25 in the Schematic editor?

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

BigBOSSJake, 2025-09-07:
 But then why do we have the more extensive scheme for the eg the the ec ?

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

00madmaker00, 2025-09-07:
> But then why do we have the more extensive scheme for the eg the the ec ?

Shouldn't it be more extensive for the EG since that's the one we are using for the first prototype? I'm not understanding your question/confusion. Try typing out a more in depth paragraph fully explaining what your concern is in detail without leaving out any specifics. That way we can take a look at this and see if there's some changes that need to be made.

           😃

Closed 2025-09-09.

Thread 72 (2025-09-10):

Phone case with slide-on camera cover

peponi17, 2025-09-10:
I think a phone case featuring a slide on camera cover would be beneficial because:

- It makes it simpler for the user to enable/disable the camera module between uses quickly, sliding the cover back and forth is a lot easier than looking for the right switch to flip.

- It reduces wear and tear on the physical camera switch over time.

- It provides protection for the camera module, making it less likely for it to get damaged.

- It adds minimal manufacturing complexity.

- It remains an optional accessory since it would be part of the case, not the phone itself.

Reference Image:

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

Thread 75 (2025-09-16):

Security Ideas for Spirit Phone

Stradexx, 2025-09-16:
Boot & Storage

Full-disk encryption (LUKS).

Cold boot always requires encryption passphrase (no biometric or PIN).

Daily Unlock

Unlock with password, 6-digit PIN or fingerprint.

PIN and password lockout: 5 fails → cooldown, exponential backoff.

Fingerprint lockout: 5 fails → cooldown; repeated failures will require PIN or Password.

Force PIN or password after long uptime, SIM/APN changes, or major settings changes.

Fingerprint Integration

Software: libfprint + fprintd + PAM; templates stored encrypted under rootfs.

First-boot wizard: enroll 1–3 fingers.

Works with Phosh, Plasma Mobile, swaylock-pam, etc.

Network Security

Default firewall: deny inbound, allow established outbound.

No exposed services; SSH server disabled by default.

Secure DNS (DoT/DoH).

User Setup

Set passphrase for encryption and sudo password or passphrase for encryption + sudo PIN for unlock. Both methods will ask to setup optional fingerprint after first boot.

Please let me know your opinions on this setup this is just some ideas I had. The password and pin will work the same I just thought differentiating them would help people understand better. I also think having a option in the setup script to make your sudo password your passphrase would be nice.

V3lectronics, 2025-09-17:
Perhaps this should be a wiki article to keep track of all ideas, which ones are implemented and which ones are not planned. Agree?

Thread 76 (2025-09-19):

Check EG25 symbol

V3lectronics, 2025-09-19:
The task is to check if the EG25 symbol in the GPS GSM schematic (value: `EG25GGC-128-SGNS`) is correct for the 256 variant of the EG25 as well.

Product page:
https://www.digikey.pl/en/products/detail/quectel/EG25GGB-256-SGNS/21272668

If yes, please rename the symbol and footprints so that there is no more confusion between the variants.

BigBOSSJake, 2025-09-19:
Take a look(this is a good website too 👀).[EG25GGB-256](https://www.snapeda.com/parts/EG25GGB-256-SGNS/Quectel/view-part/)  ,[EG25GGC-128](https://www.snapeda.com/parts/EG25GGC-128-SGNS/Quectel/view-part/)

V3lectronics, 2025-09-22:
Ok I checked all 3 sections of the symbol, I see both are the same on the website and the same as the one we have in KiCad except:
- current KiCad has multiple vbat pins
- reserved pins
- separate gnds (idk if that even matters in terms of symbols)

So I would stick with the one we have currently!

Closed 2025-10-01.

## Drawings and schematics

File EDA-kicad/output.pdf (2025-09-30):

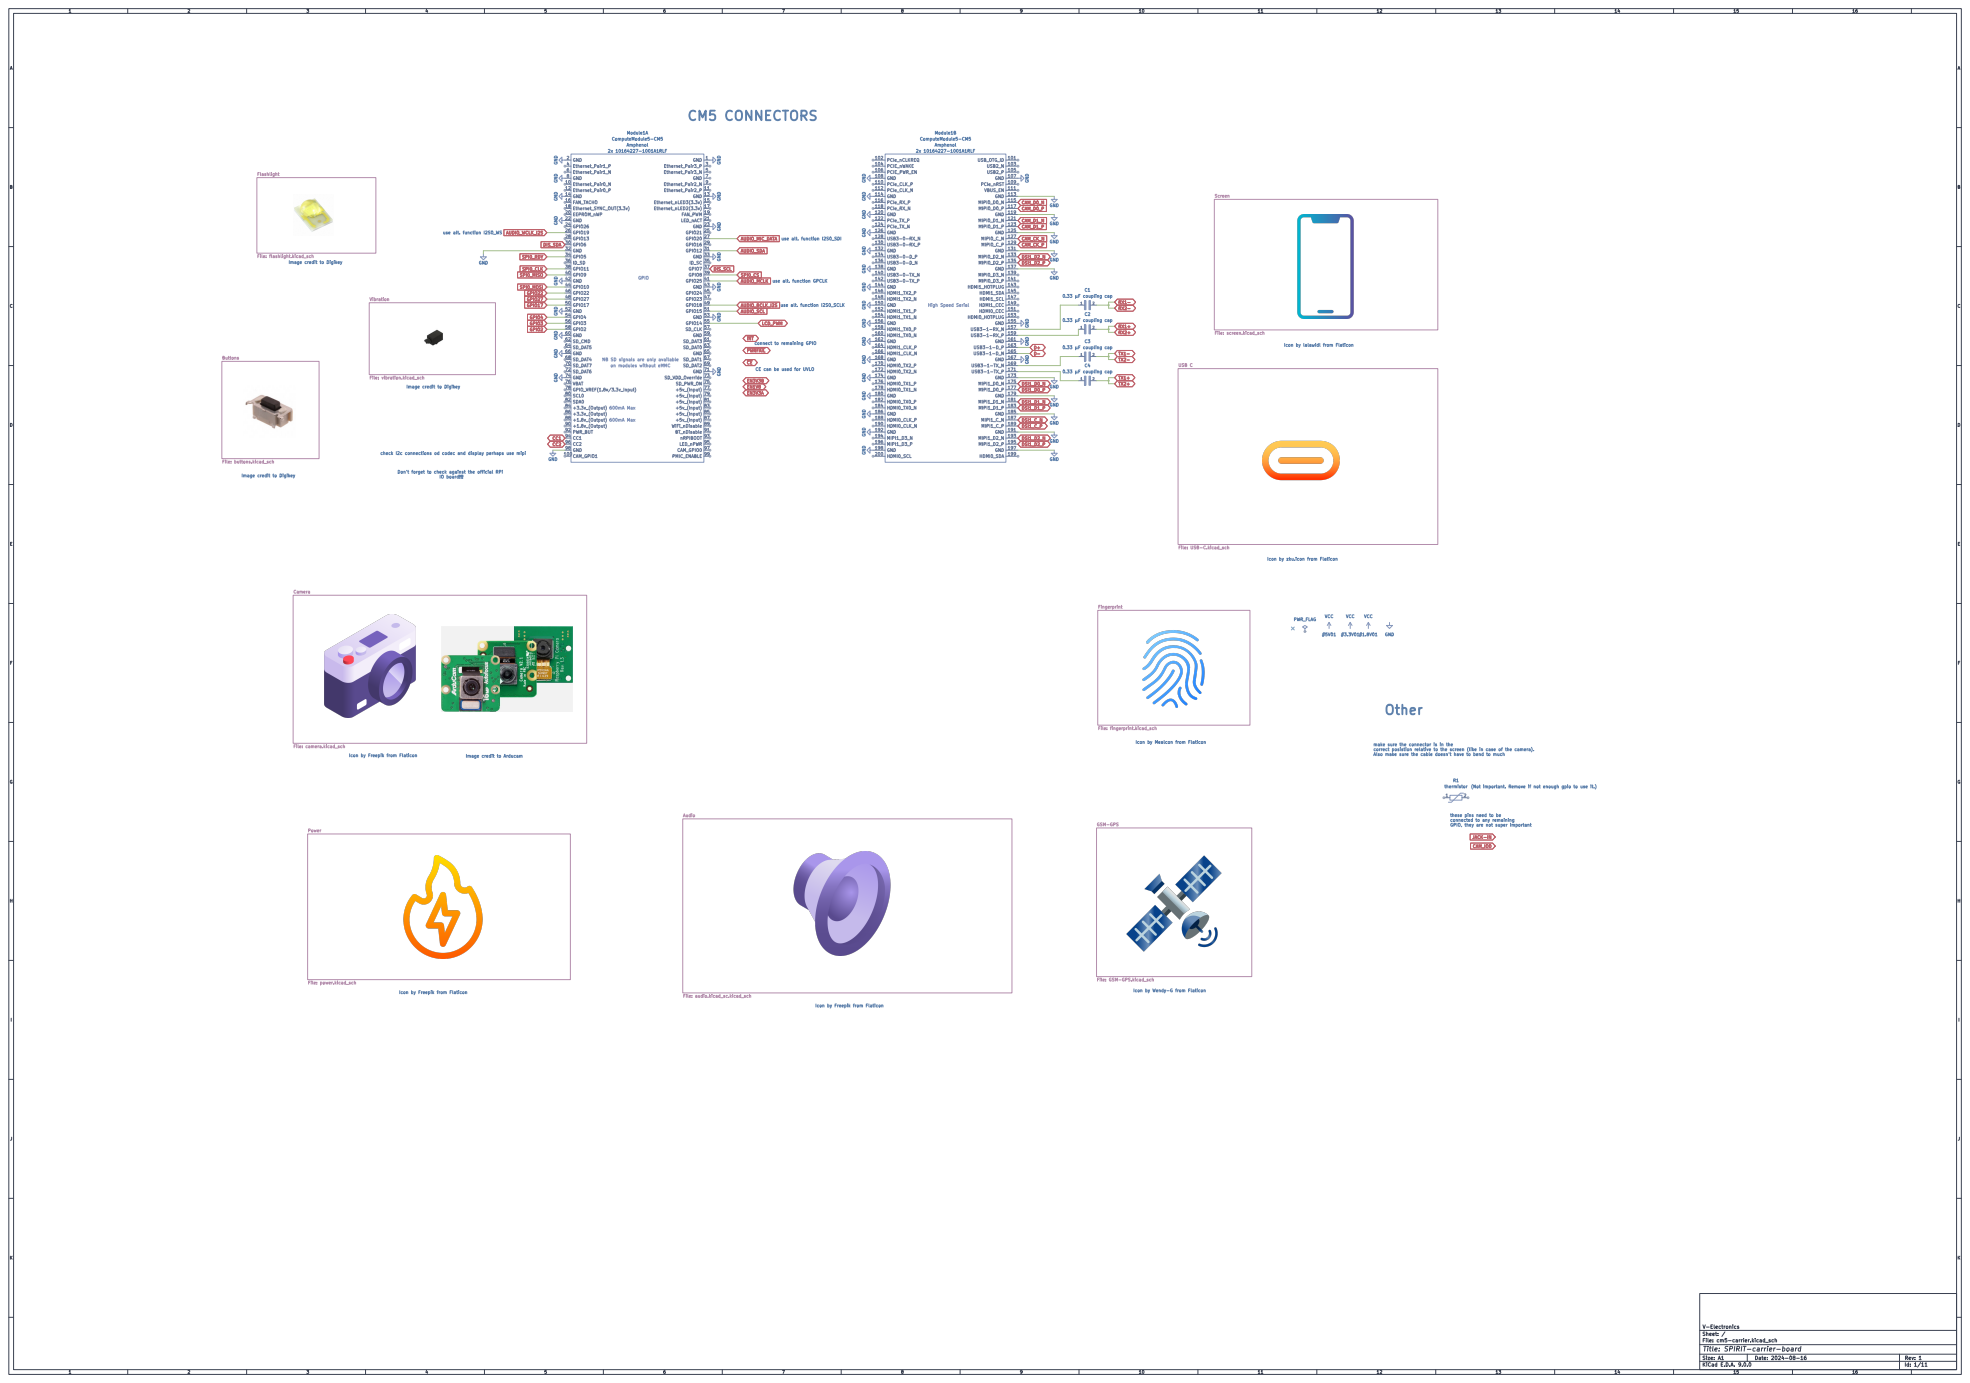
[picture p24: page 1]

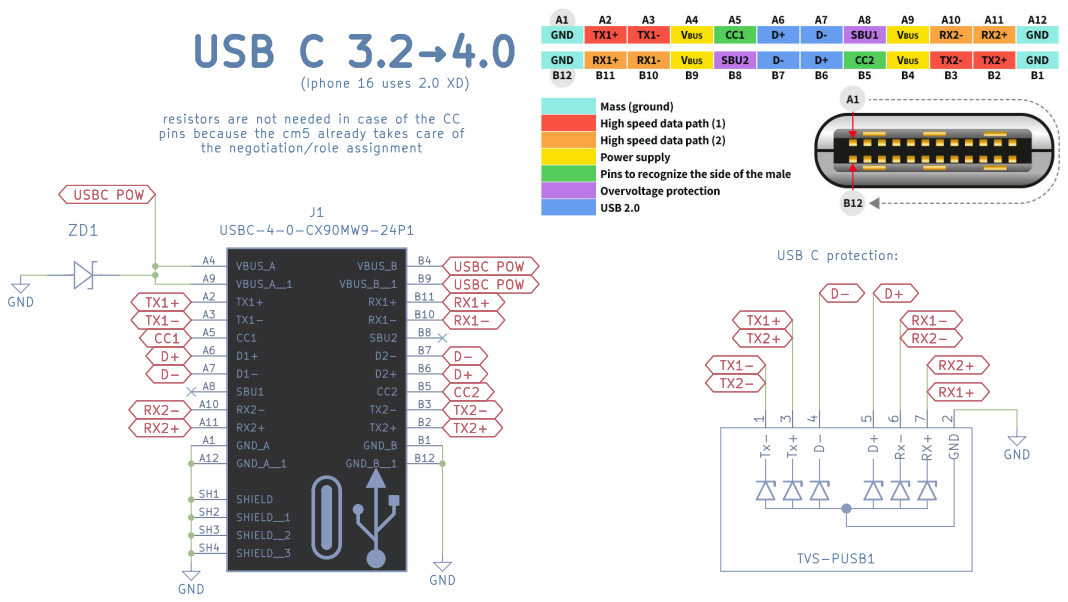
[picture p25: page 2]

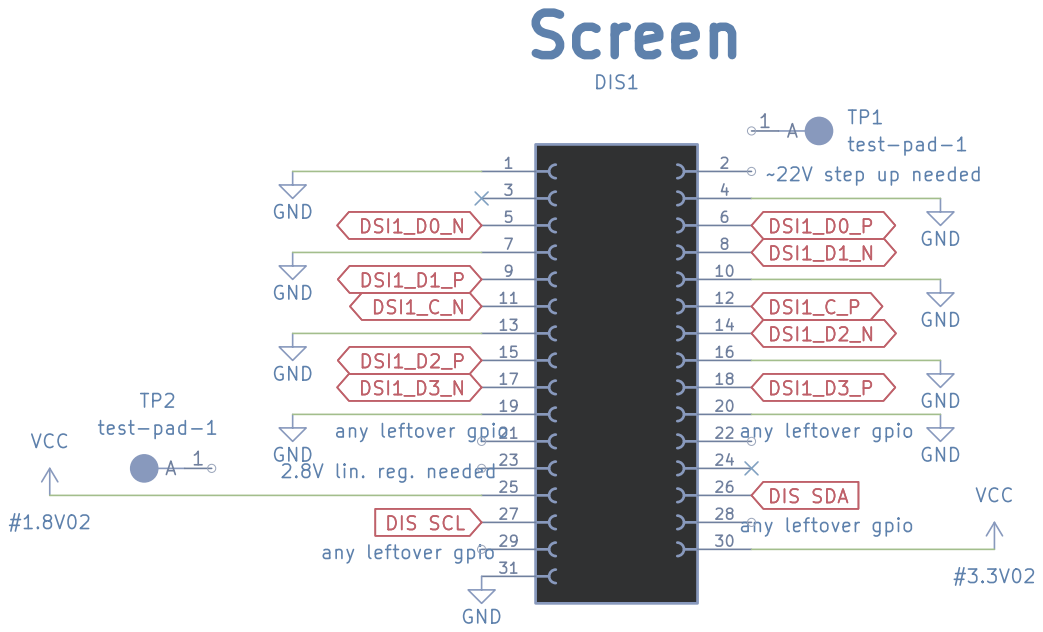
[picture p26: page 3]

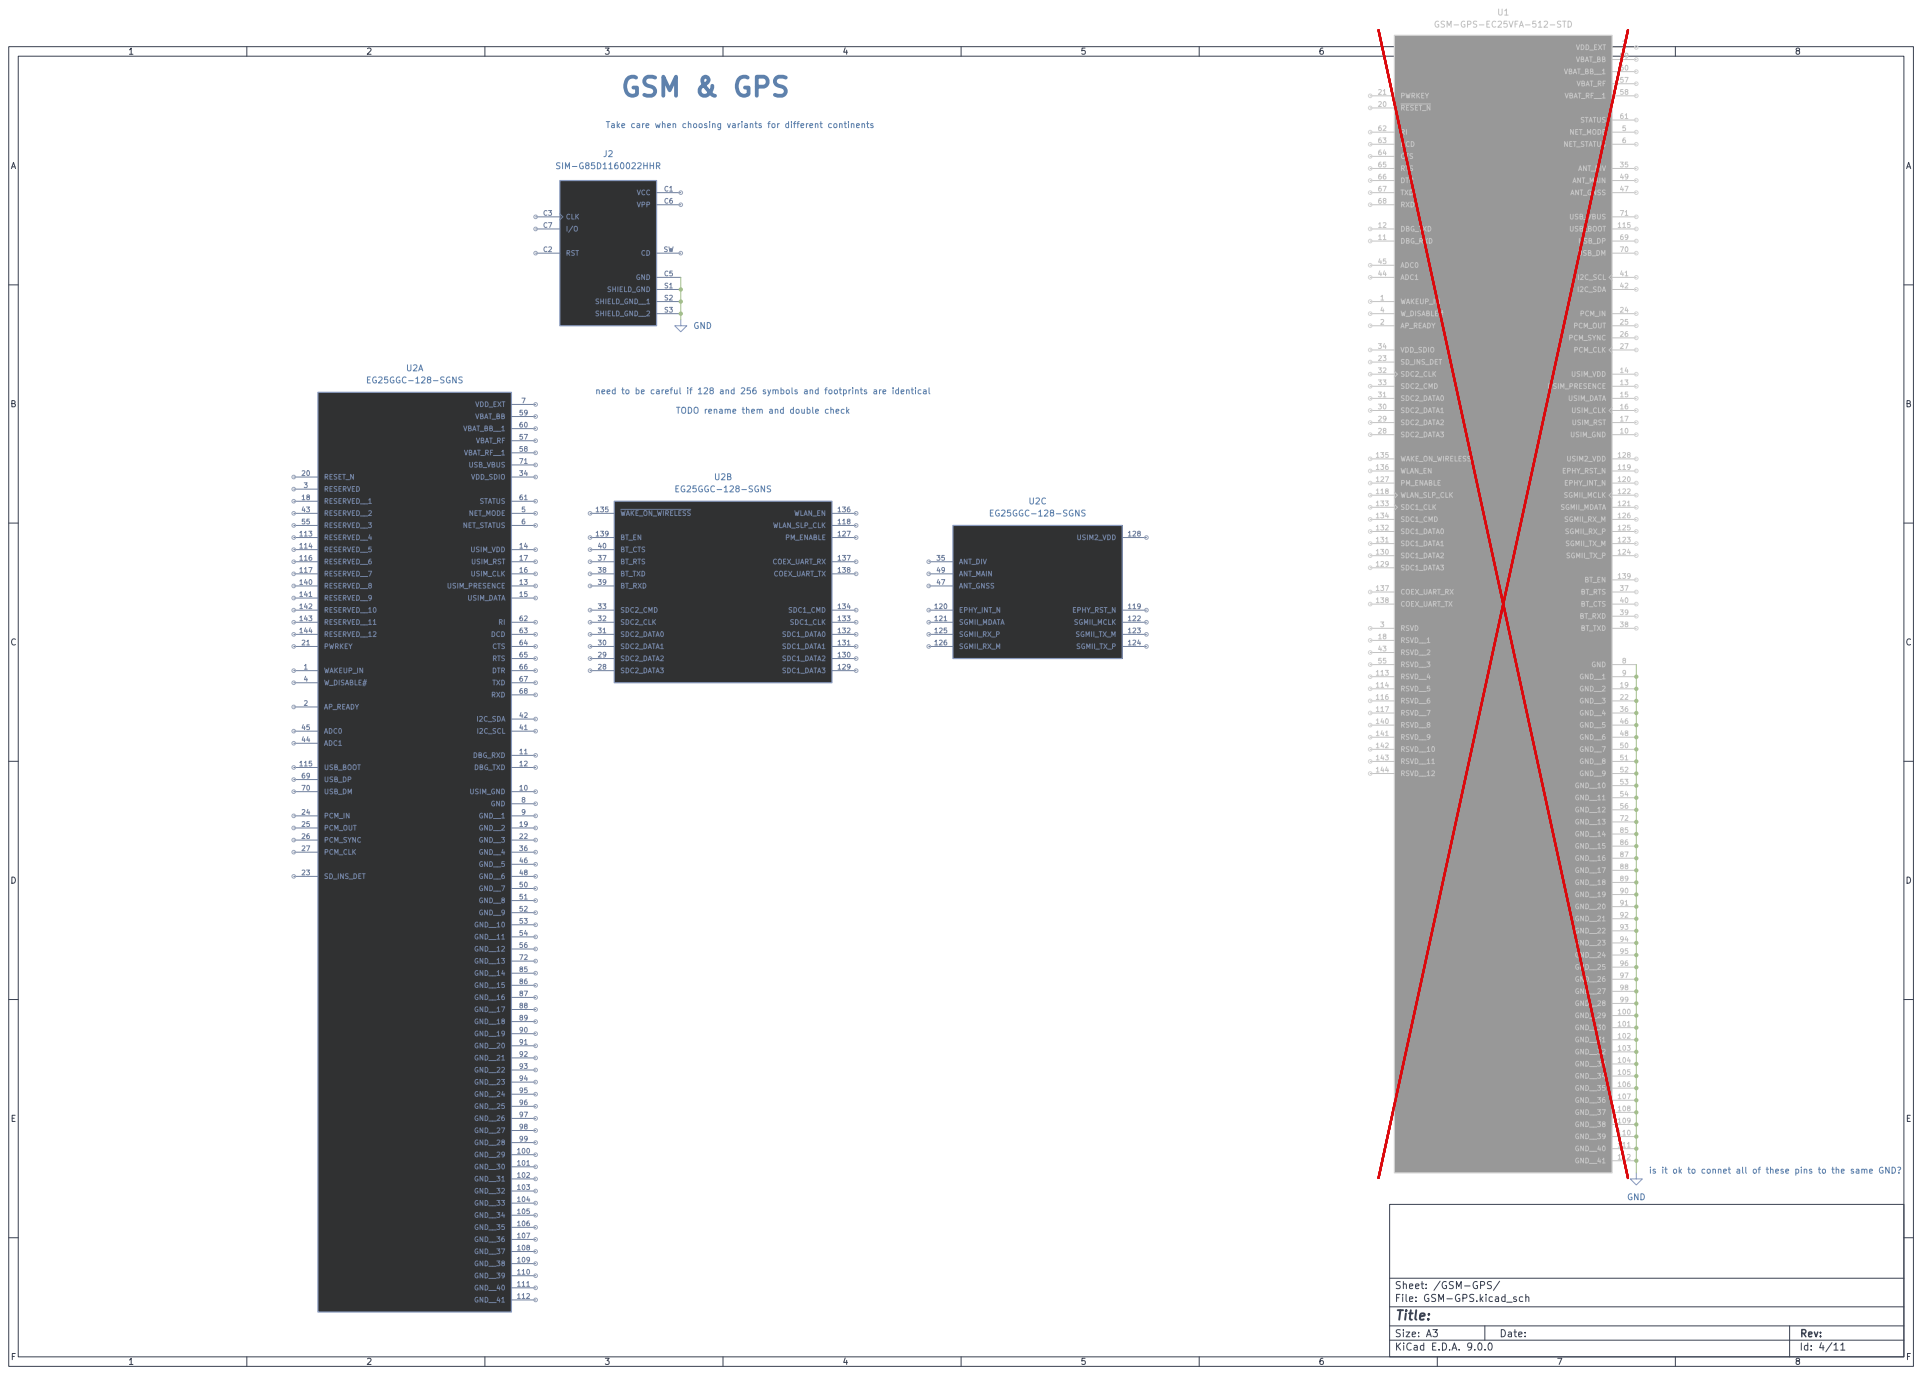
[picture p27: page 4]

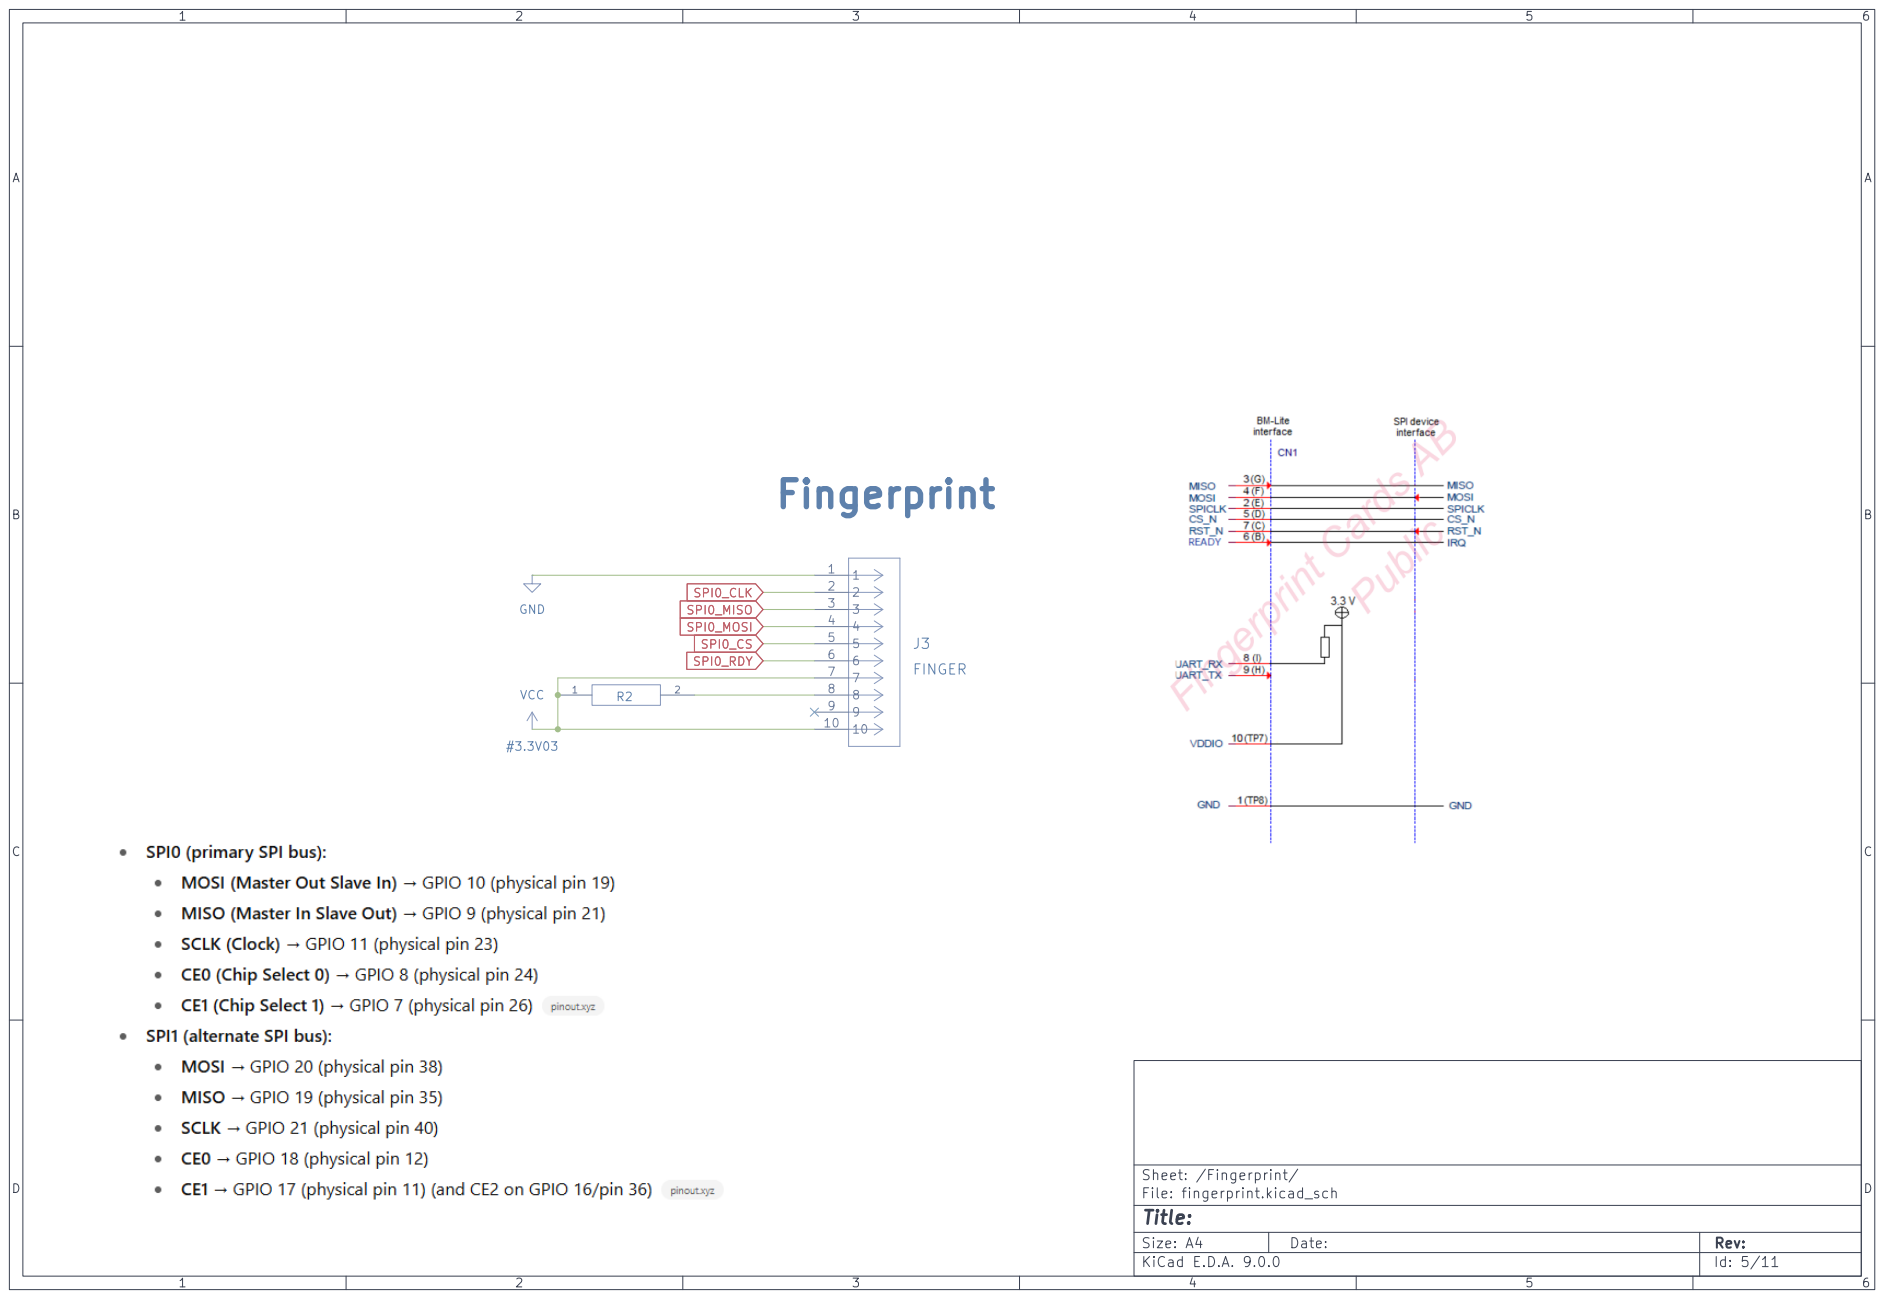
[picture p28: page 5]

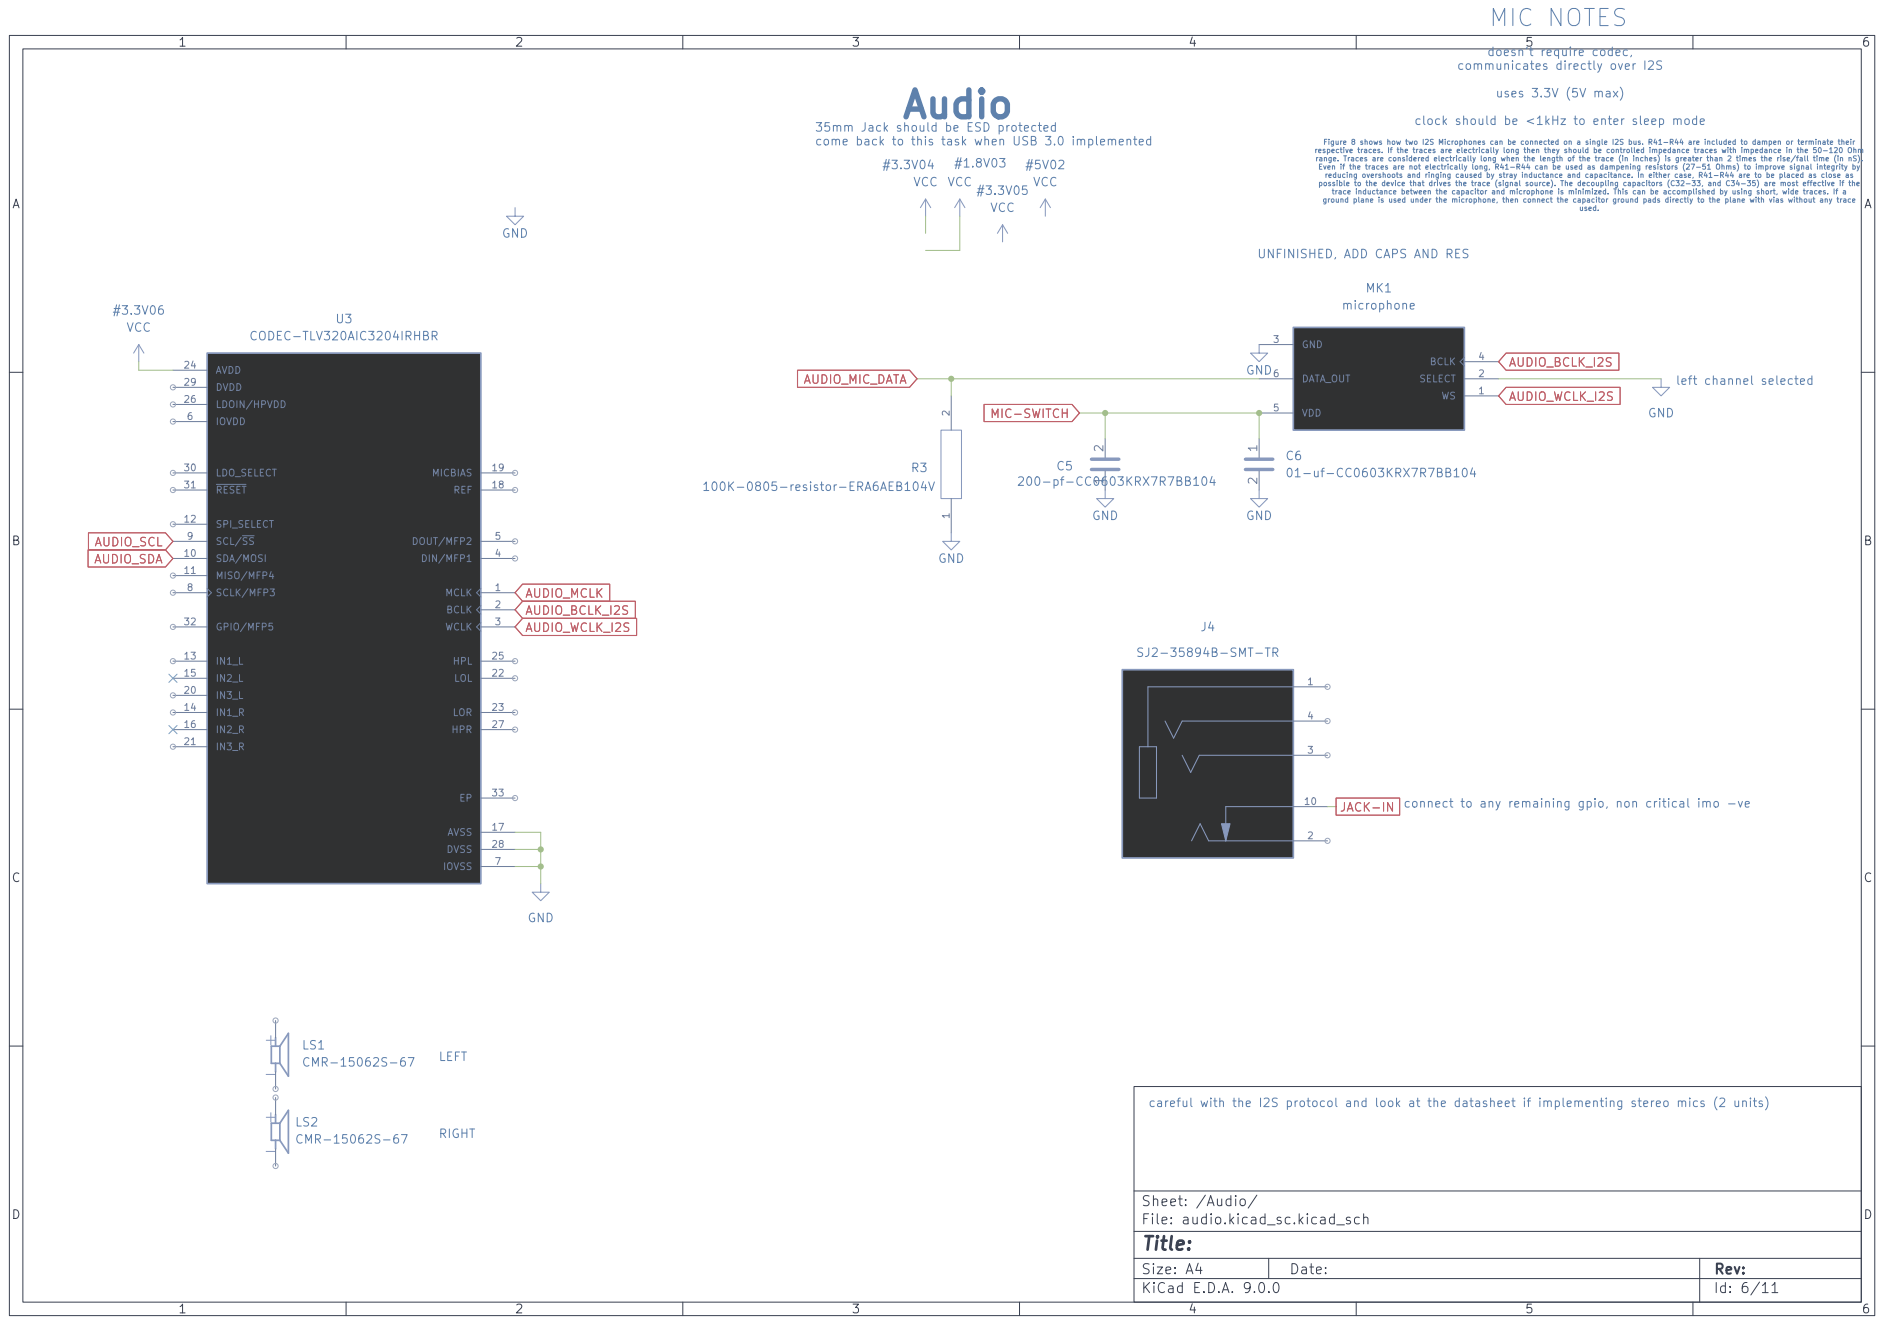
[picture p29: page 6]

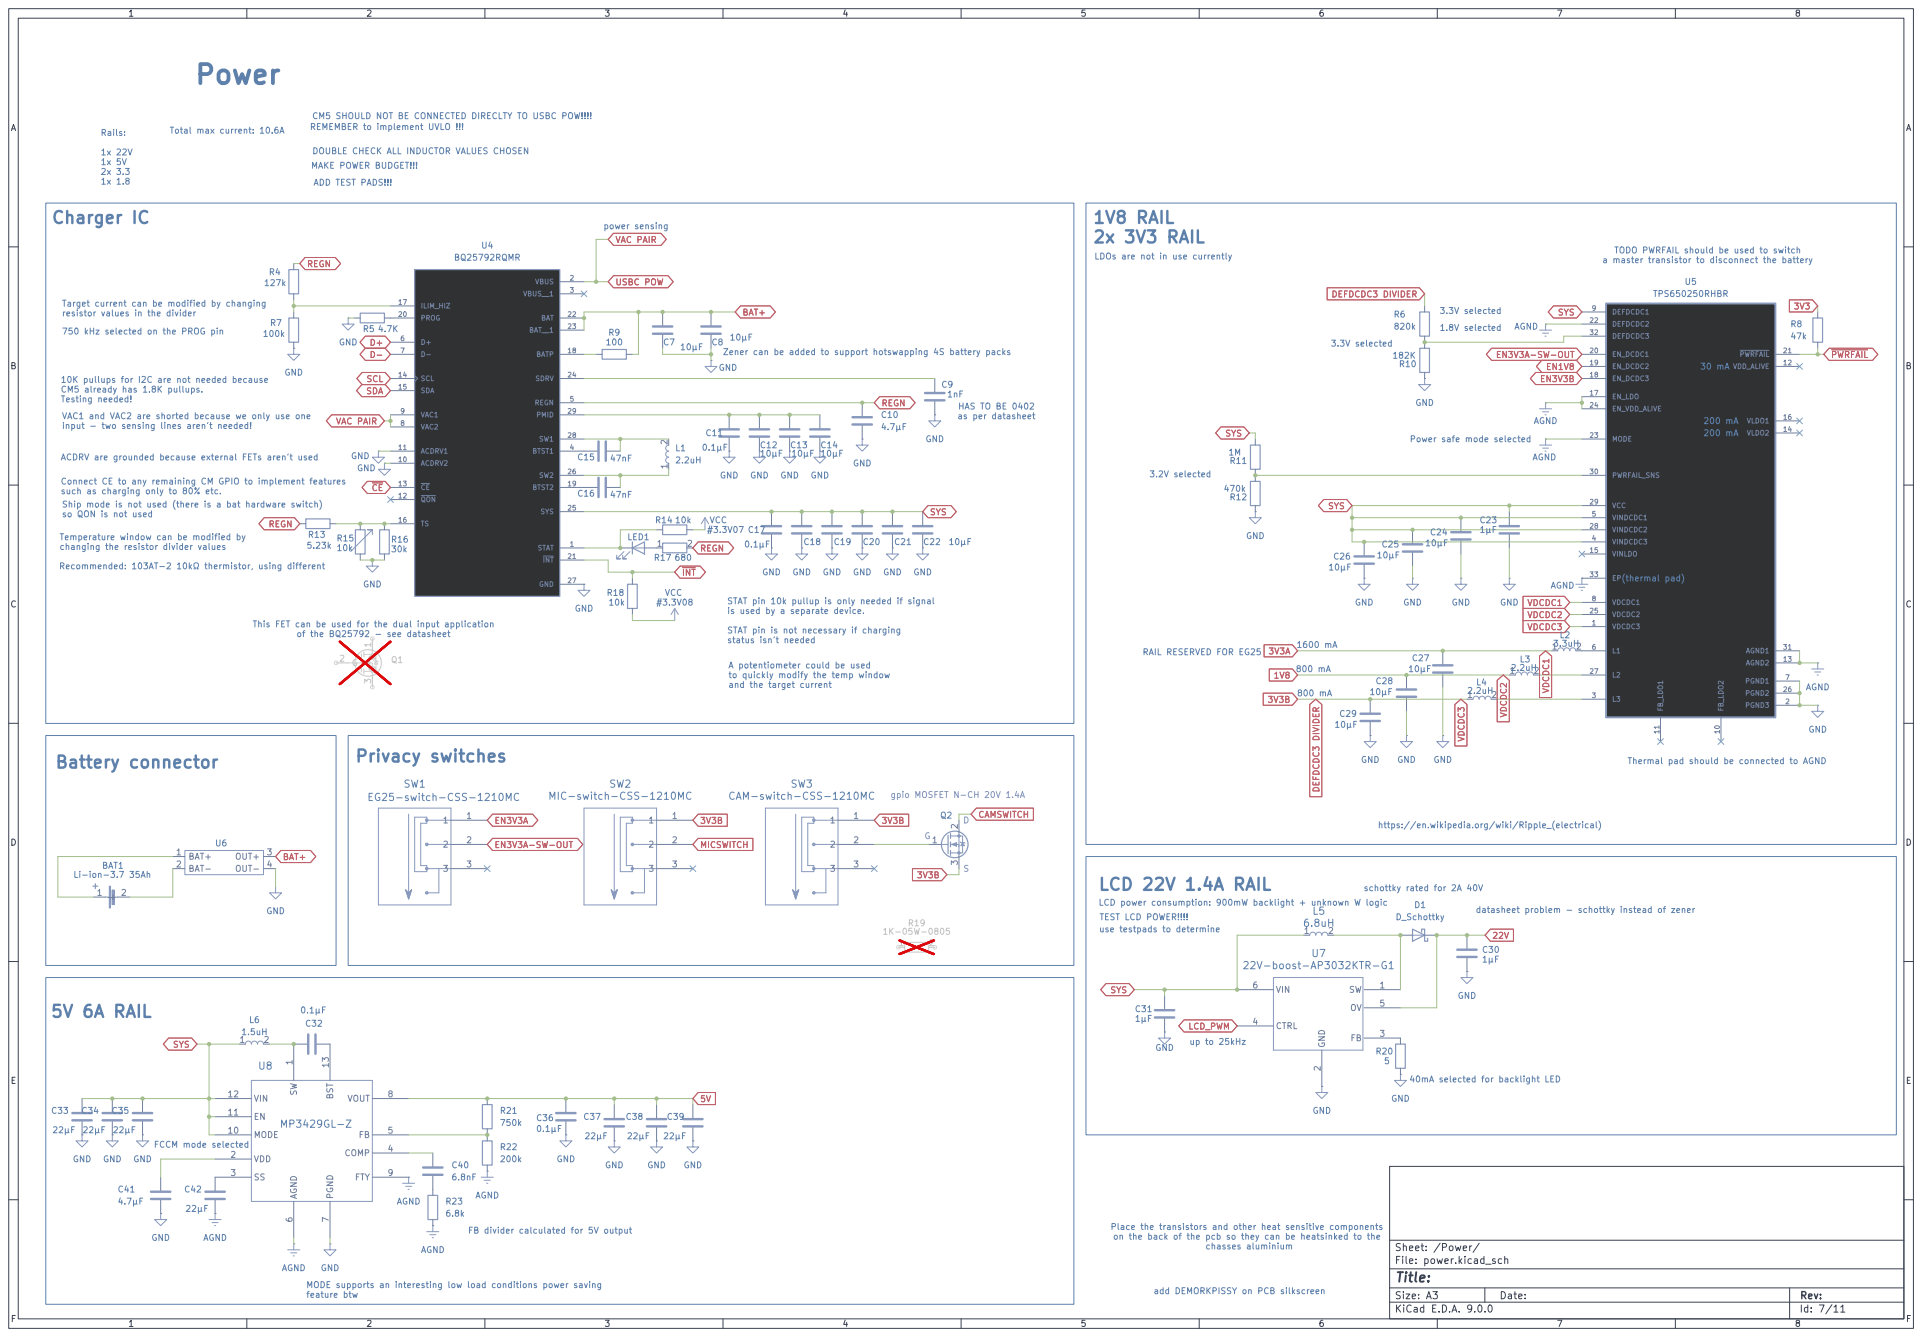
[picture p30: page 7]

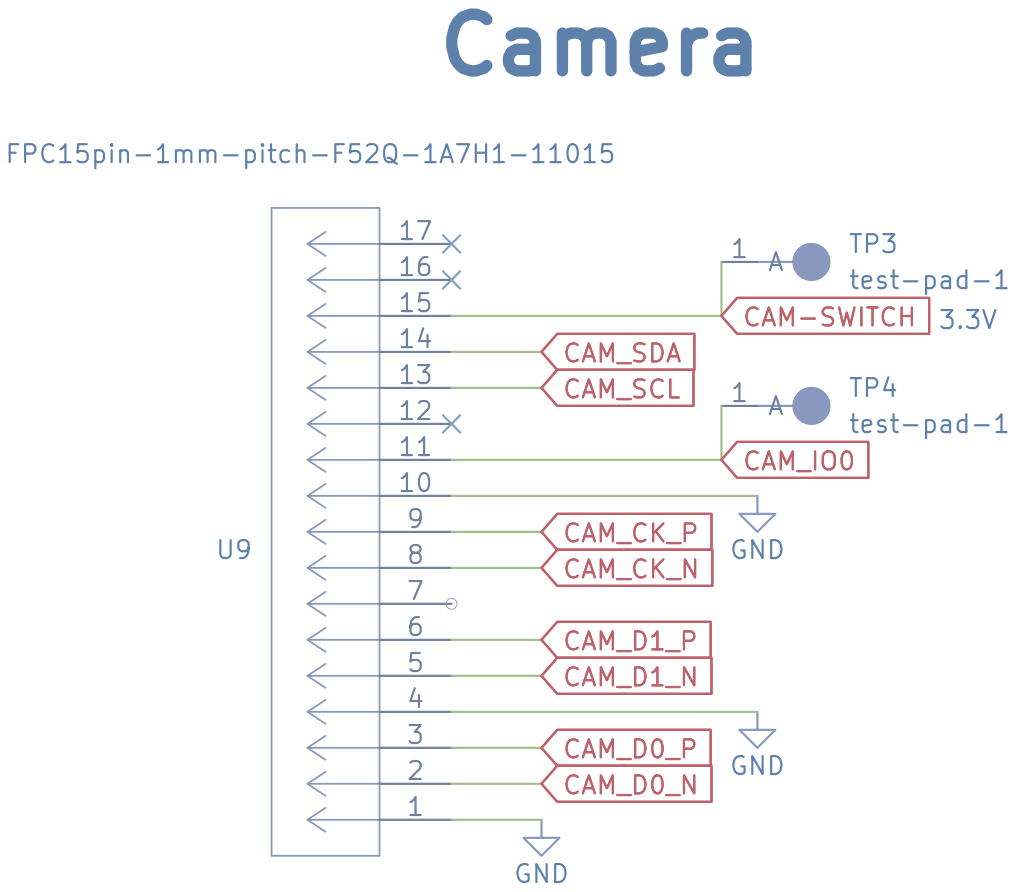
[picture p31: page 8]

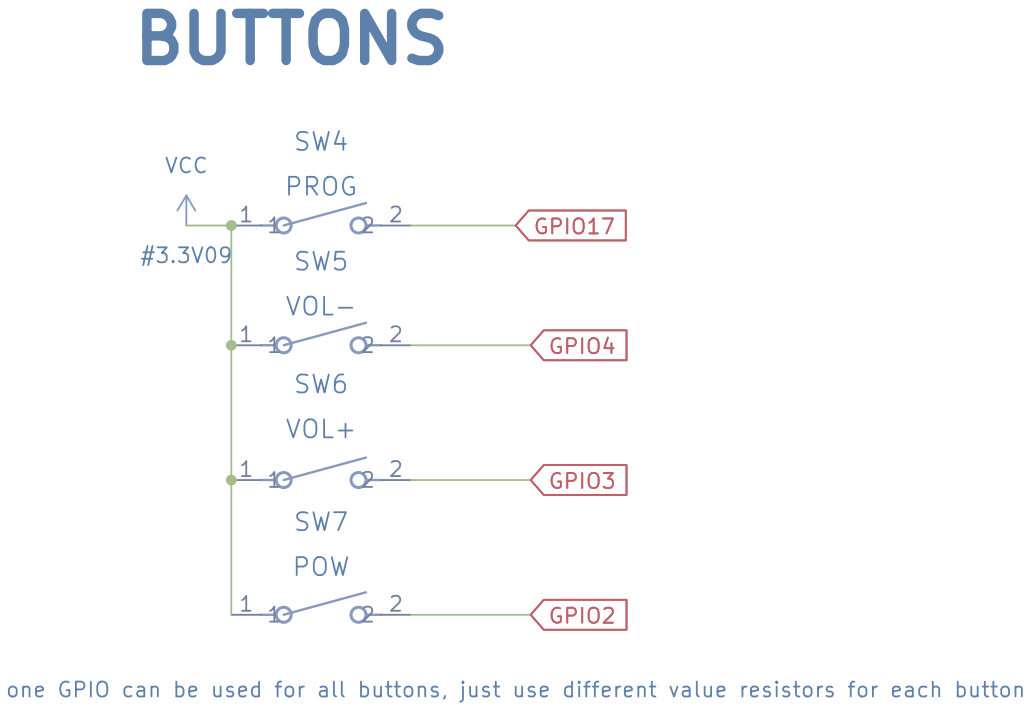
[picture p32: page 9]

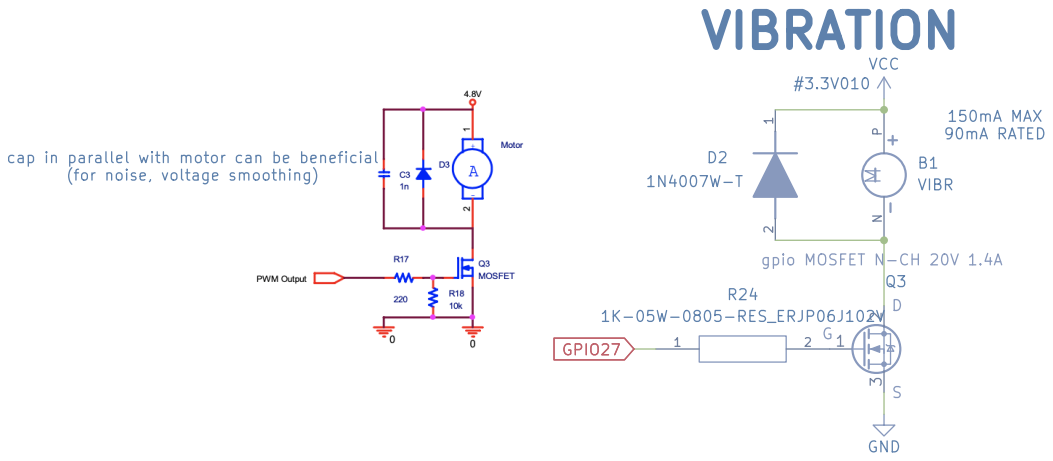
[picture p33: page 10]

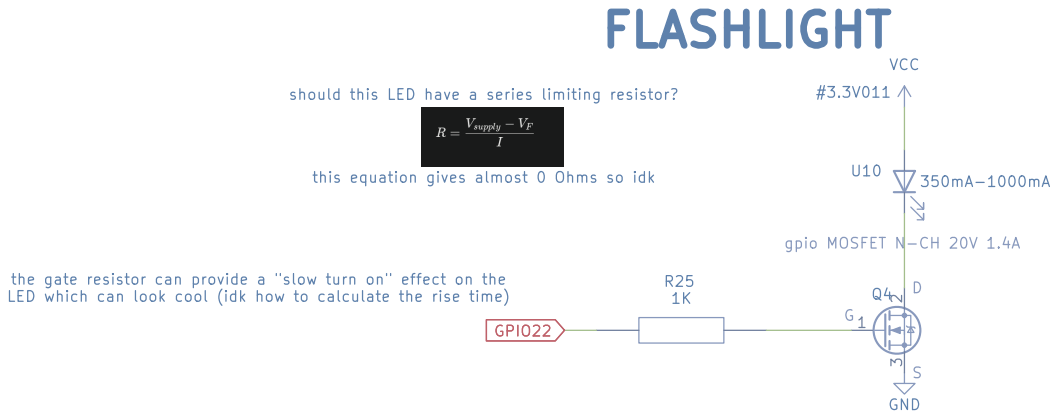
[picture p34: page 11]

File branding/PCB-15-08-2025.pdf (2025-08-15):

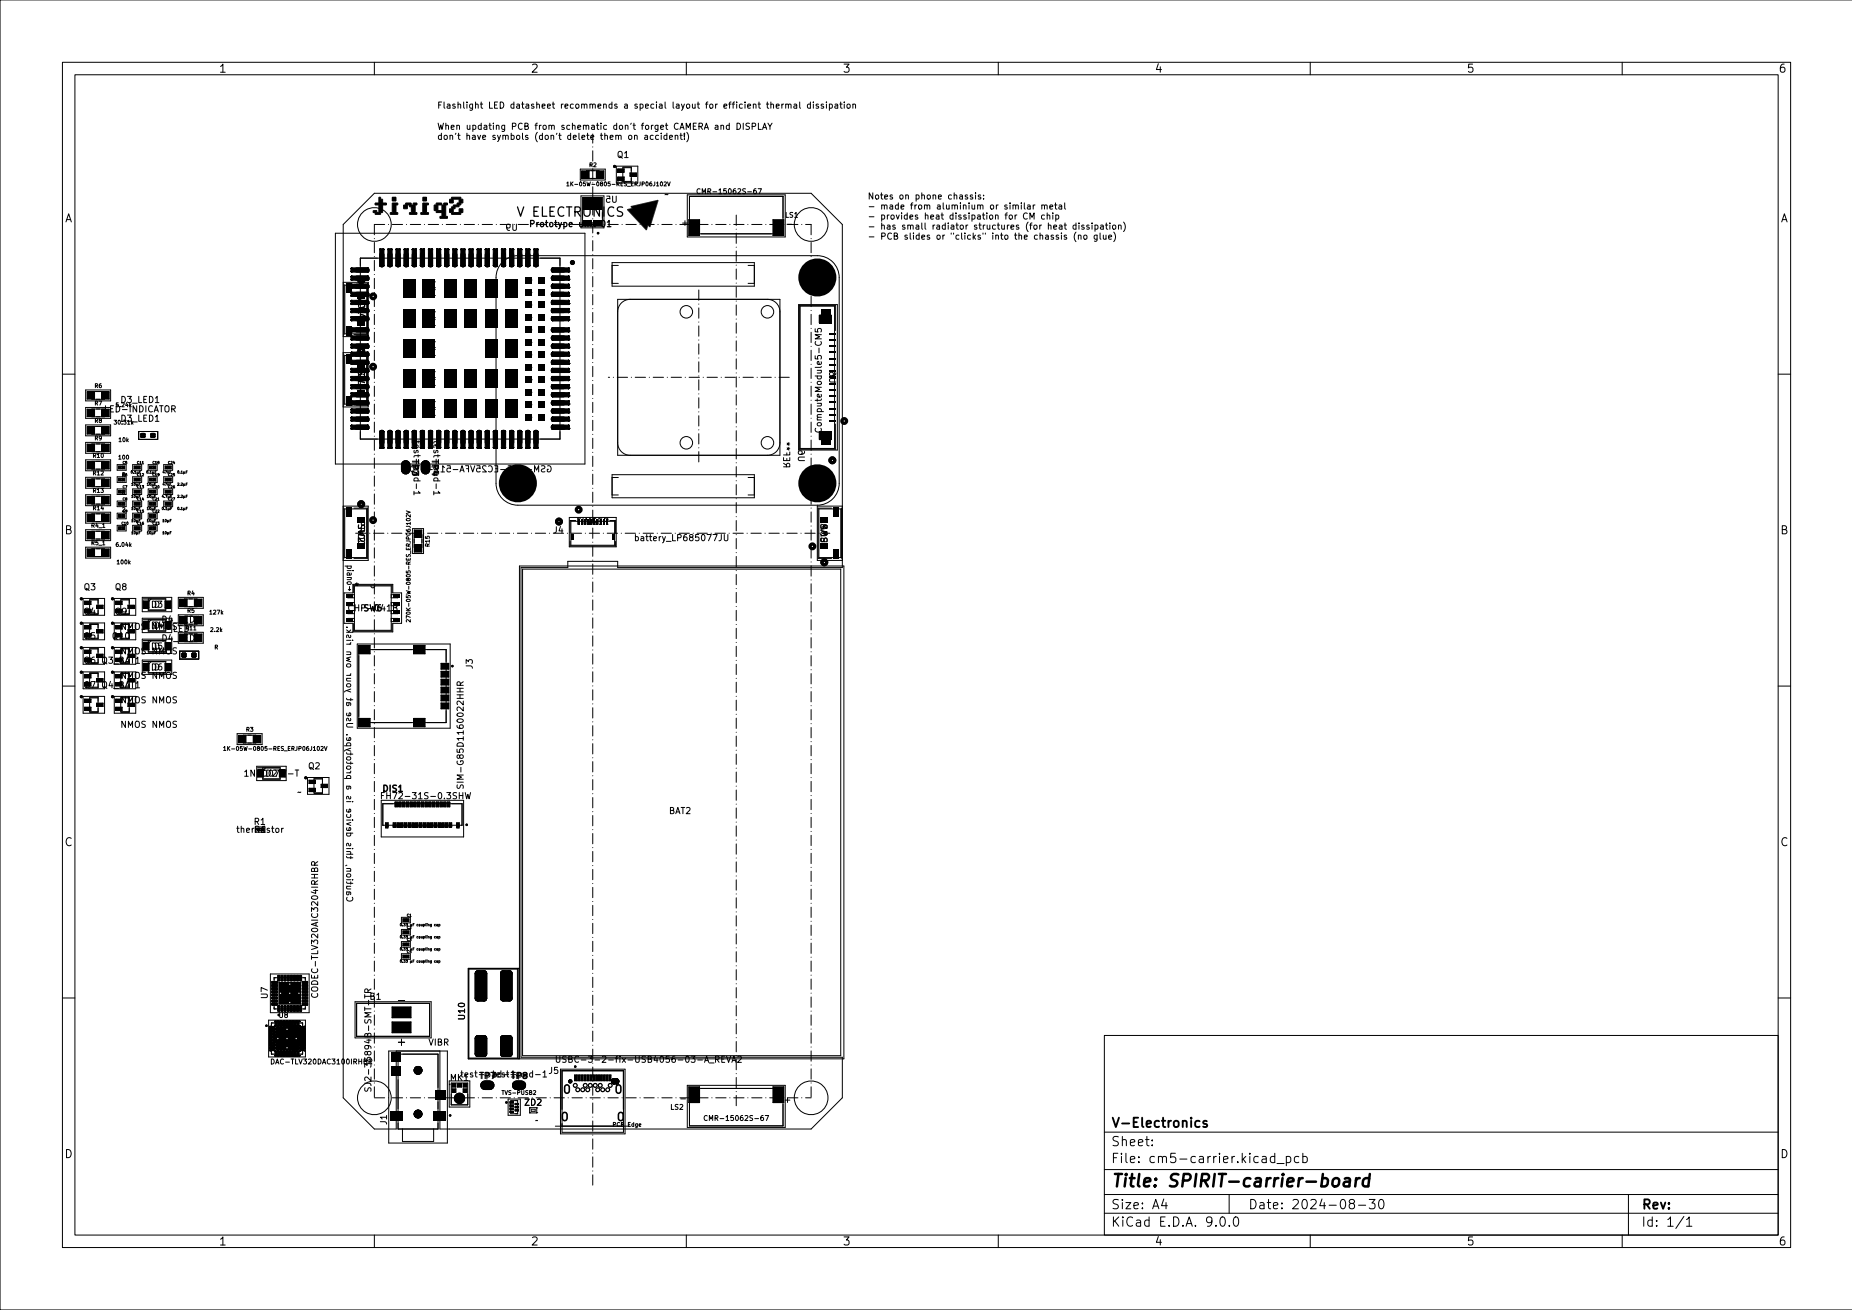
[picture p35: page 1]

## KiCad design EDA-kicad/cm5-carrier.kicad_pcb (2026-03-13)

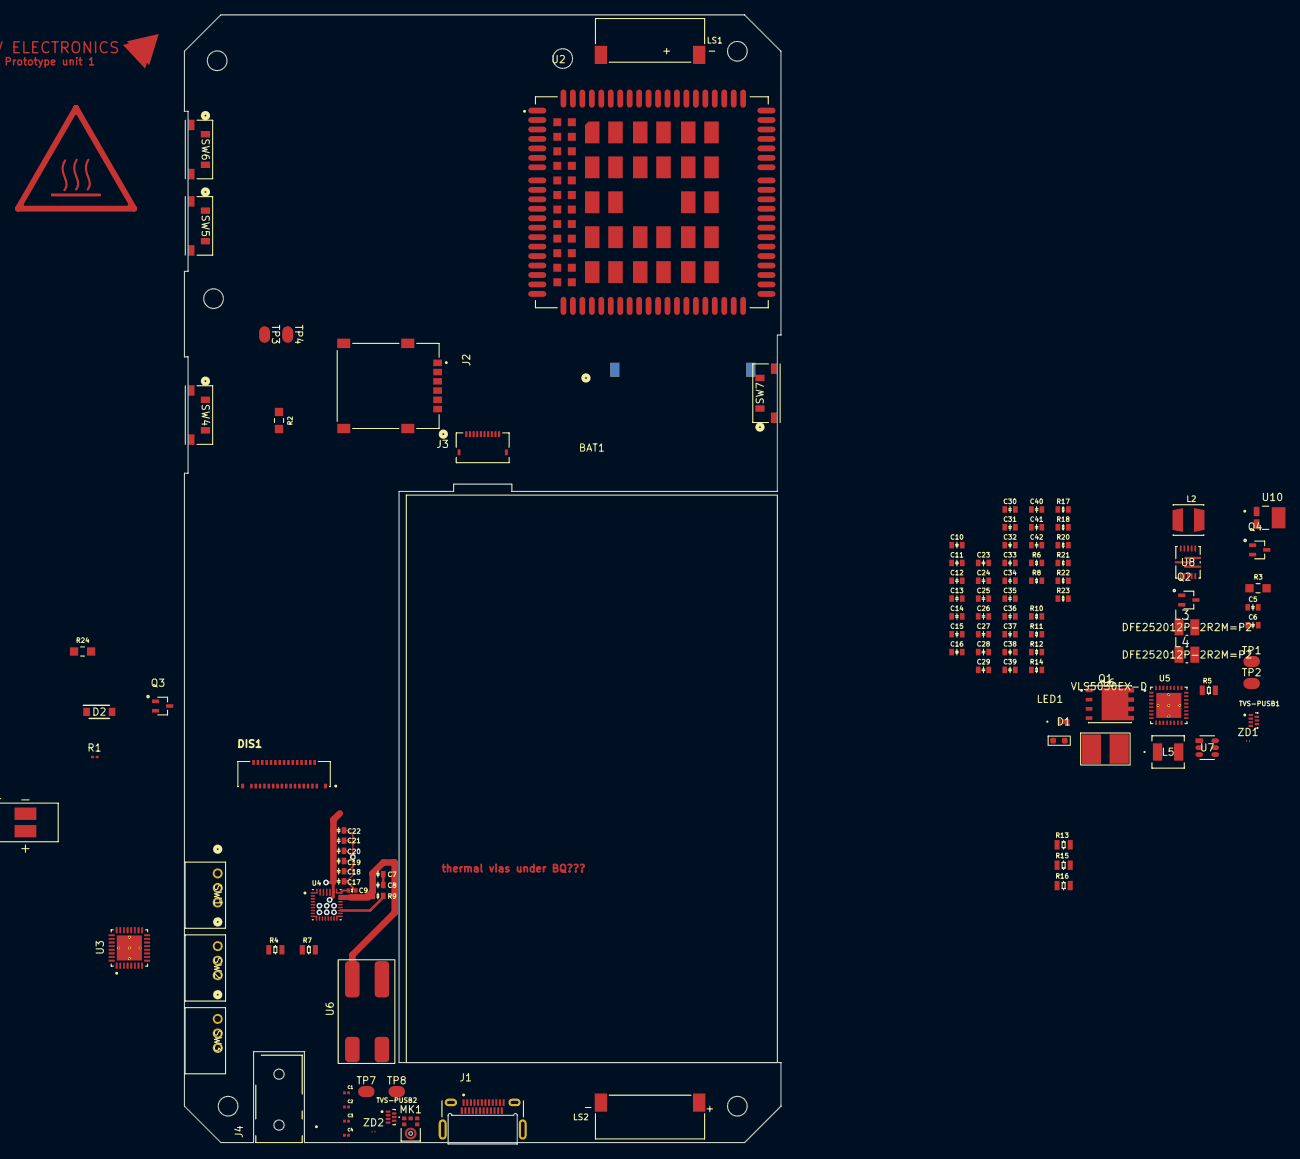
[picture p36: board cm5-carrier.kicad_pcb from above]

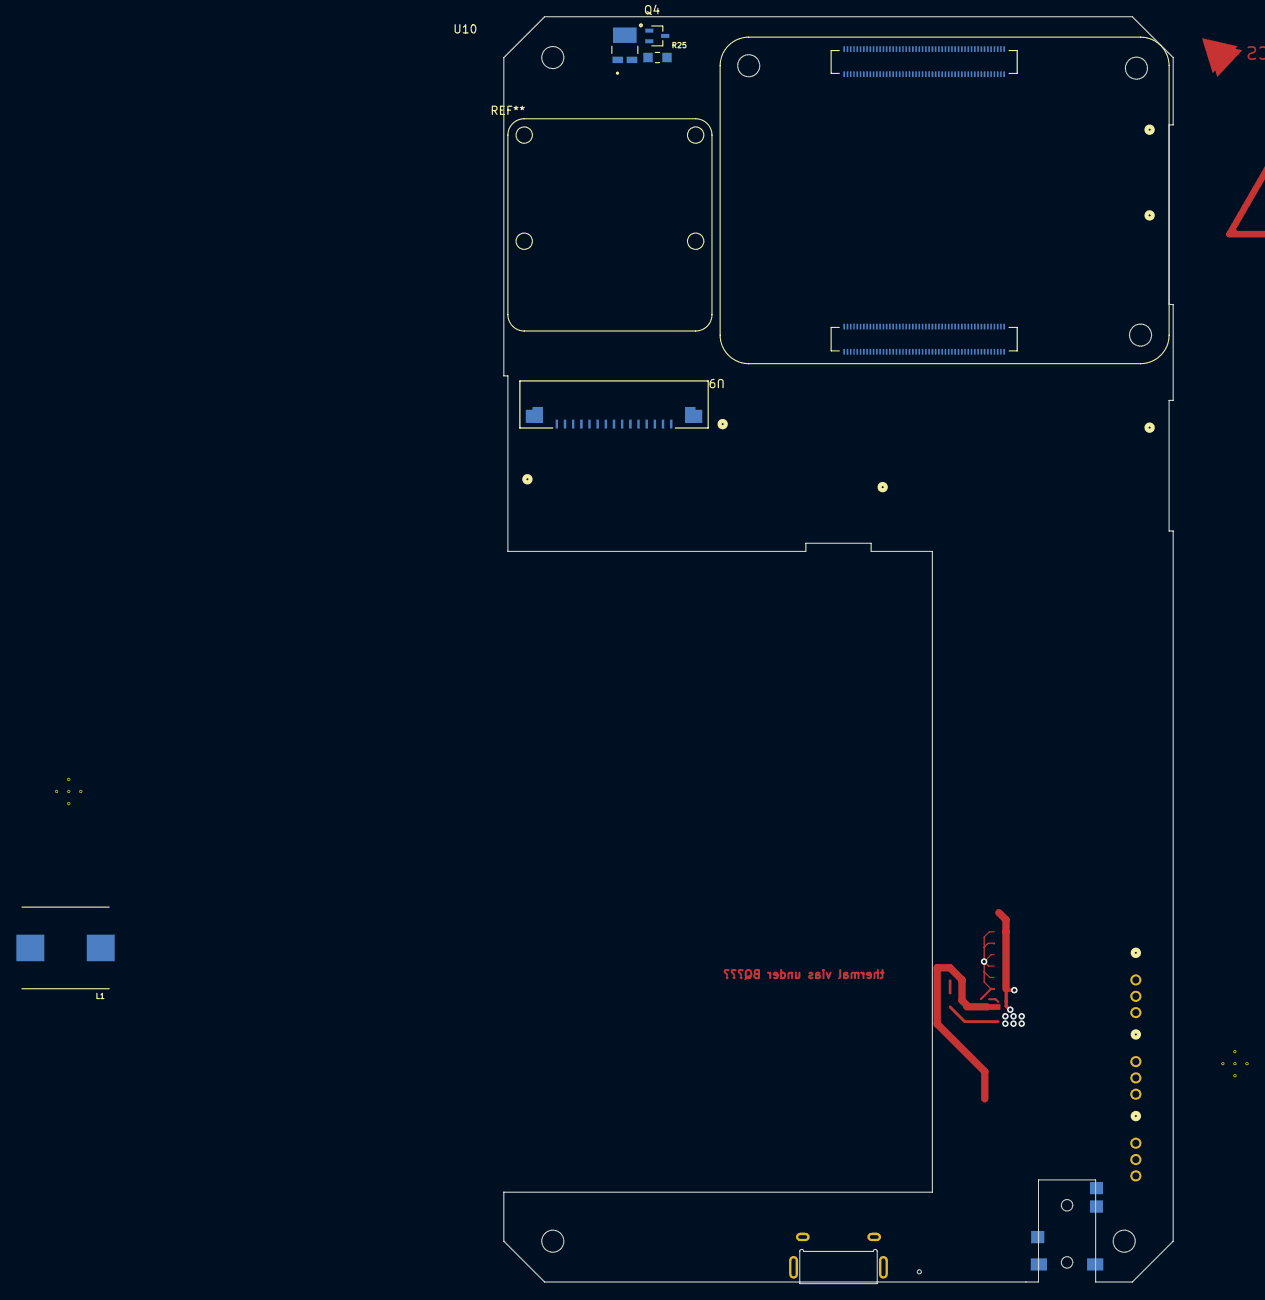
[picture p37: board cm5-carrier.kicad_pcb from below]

Board: 6 copper layers, 82.0 x 155.0 mm, 118 parts (6 on the bottom side), 94 nets.

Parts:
B1: VIBR; VIBRATION-PUI_HD-EMB1205-3-SC-R
BAT1: Li-ion-3.7 35Ah; battery_37V3500mAhLP685077JU
C1, C2, C3, C4: 0.33 µF coupling cap; USBC_capacitor_CAPC0603X33N
C5: 200-pf-CC0603KRX7R7BB104; 0603-capacitor
C6: 01-uf-CC0603KRX7R7BB104; 0603-capacitor
C7, C8, C12, C13, C14, C18, C19, C20, C21, C22, C24, C25, C26, C27, C28, C29: 10μF; 0603-capacitor
C9: 1nF 50V; 0402-capacitor
C10, C41: 4.7μF; 0603-capacitor
C11, C17, C32, C36: 0.1μF; 0603-capacitor
C15, C16: 47nF; 0603-capacitor
C23, C30, C31: 1μF; 0603-capacitor
C33, C34, C35, C37, C38, C39, C42: 22μF; 0603-capacitor
C40: 6.8nF; 0603-capacitor
D1: D_Schottky; schottky-diode-CR_DSN2_152AB-C_OSI
D2: 1N4007W-T; flyback-diode-SODFL3818X130N
DIS1: FH72-31S-0.3SHW; HRS_FH72-31S-0.3SHW
J1: USBC-4-0-CX90MW9-24P1; USB-4-0-HIROSE_CX90MW9-24P1
J2: SIM-G85D1160022HHR; SIM-AMPHENOL_G85D1160022HHR
J3: FINGER; 10PIN
J4: SJ2-35894B-SMT-TR; 35mmJACK-CUI_SJ2-35894B-SMT-TR
L1: 2.2uH; 2-2uh-inductorIND_ETQP4M2R2KVC
L2: 3.3uH; 3-3uH-MURATA_LQH44PN3R3MPRL
L3, L4: 2.2uH; 2-2uH-inductor-INDC2520X120N
L5: 6.8uH; 6-8uH-inductor-LQH44PN6R8MPRLIND_LQH44PN_PR_MUR
L6: 1.5uH; 1-5uH-inductor-VLS5030EX-D
LED1: 5mA 2V Fv; LED-INDICATOR-RED-QBLP601-R5
LS1, LS2: CMR-15062S-67; SPEAKER_CMR-15062S-67
MK1: microphone; microphone_SPH0645LM4H-B
Module1: ComputeModule5-CM5; Raspberry-Pi-5-Compute-Module
Q1: NMOS-BSC0902NSIATMA1-PG-TDSON-8-6-IC_ISC037N03L5ISATMA1
Q2, Q3, Q4, Q4#2: gpio-driver-transistor-fix-SOT65P210X110-3N
R1: thermistor; thermistor-NTC0201Z_P63XP33_PAN
R2: 270K-05W-0805-RES_ERJP06J102V; 1K-05W-0805-RES_ERJP06J102V
R3: 100K-0805-resistor-ERA6AEB104V; 100K-0805-resistor-RES_ERA6AEB104V
R4: 127k; 0805-resistor
R5: 4.7K; 0805-resistor
R6: 820k; 0603-resistor
R7: 100k; 0805-resistor
R8: 47k; 0603-resistor
R9: 100; 0603-resistor
R10: 182K; 0603-resistor
R11: 1M; 0603-resistor
R12: 470k; 0603-resistor
R13: 5.23k; 0805-resistor
R14, R18: 10k; 0603-resistor
R15: 10k; 0805-resistor
R16: 30k; 0805-resistor
R17: 680; 0603-resistor
R20: 5; 0603-resistor
R21: 750k; 0603-resistor
R22: 200k; 0603-resistor
R23: 6.8k; 0603-resistor
R24: 1K-05W-0805-RES_ERJP06J102V
R25: 1K; 1K-05W-0805-RES_ERJP06J102V
SW1: EG25-switch-CSS-1210MC; privacy-switch-SW3_CSS-1210MC_NDC
SW2: MIC-switch-CSS-1210MC; privacy-switch-SW3_CSS-1210MC_NDC
SW3: CAM-switch-CSS-1210MC; privacy-switch-SW3_CSS-1210MC_NDC
SW4: PROG; buttonSW_TL3330_EWI
SW5: VOL-; buttonSW_TL3330_EWI
SW6: VOL+; buttonSW_TL3330_EWI
SW7: POW; buttonSW_TL3330_EWI
TP1, TP2, TP3, TP4, TP7, TP8: test-pad-1
TVS-PUSB1, TVS-PUSB2: TVS-array-IC_PUSB3AB6Z
U2: EG25GGC-128-SGNS; XCVR_EG25GGC-128-SGNS
U3: CODEC-TLV320AIC3204IRHBR; CODEC-QFN50P500X500X100-33N
U4: BQ25792RQMR; charger-bq25792-QFN40P400X400X100-29N
U5: TPS650250RHBR; TPS650250-IC_ADS125H01IRHBT
U6: BAT-CONNECTOR-FLTS22WR00
U7: 22V-boost-AP3032KTR-G1; SOT23-6_DIO
U8: MP3429GL-Z; QFN-3x4_MP3429_MNP
U9: FPC15pin-1mm-pitch-F52Q-1A7H1-11015; FPC15pin-1mm-pitch-CONN_F52Q-1A7H1-11015_AMP
U10, U10#2: Flash-LED-Lumiled; LUMILED-DIODFN449X305X210-3N
ZD1, ZD2: protection-PESD5V0C1USFYL; USB-ESD-protection-diode-PESD5V0C1USFYL-SOD962-2_DSN0603-2_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

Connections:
1V8: C28.1, DIS1.25, L3.1, U5.25 (VDCDC2)
3V3A: C27.1, L2.1, U5.8 (VDCDC1)
3V3B: C29.1, DIS1.30, L4.1, Q2.3 (S), R6.1, SW2.1, SW3.1, U5.1 (VDCDC3)
5V: C36.1, C37.1, C38.1, C39.1, R21.1, U8.8 (VOUT)
22V: C30.1, D1.1 (K), DIS1.2, U7.5 (OV)
AGND: C42.2, R22.2, R23.2, U5.13 (AGND2), U5.17 (EN_LDO), U5.22 (DEFDCDC2), U5.23 (MODE), U5.24 (EN_VDD_ALIVE), U5.31 (AGND1), U5.33 (EP), U8.6 (AGND), U8.9 (FTY)
AUDIO_BCLK_I2S: MK1.4 (BCLK), Module1.49 (GPIO18), U3.2 (BCLK)
AUDIO_MCLK: Module1.41 (GPIO25), U3.1 (MCLK)
AUDIO_MIC_DATA: MK1.6 (DATA_OUT), Module1.27 (GPIO20), R3.2
AUDIO_SCL: Module1.51 (GPIO15), U3.9 (SCL/~SS)
AUDIO_SDA: Module1.31 (GPIO12), U3.10 (SDA/MOSI)
AUDIO_WCLK_I2S: MK1.1 (WS), Module1.26 (GPIO19), U3.3 (WCLK)
BACKLIGHT-: C5.1, C6.2, C7.2, C8.2, C9.2, C10.2, C11.2, C12.2, C13.2, C14.2, C17.2, C18.2, C19.2, C20.2, C21.2, C22.2, C23.2, C24.2, C25.2, C26.2, C27.2, C28.2, C29.2, C30.2, C31.2, C33.2, C34.2, C35.2, C36.2, C37.2, C38.2, C39.2, C41.1, DIS1.1, DIS1.4, DIS1.7, DIS1.10, DIS1.13, DIS1.16, DIS1.19, DIS1.20, DIS1.31, J1.A1 (GND_A), J1.A12 (GND_A__1), J1.B1 (GND_B), J1.B12 (GND_B__1), J1.SH1 (SHIELD), J1.SH2 (SHIELD__1), J1.SH3 (SHIELD__2), J1.SH4 (SHIELD__3), J2.C5 (GND), J2.S1 (SHIELD_GND), J2.S2 (SHIELD_GND__1), J2.S3 (SHIELD_GND__2), J3.1, MK1.2 (SELECT), MK1.3 (GND), Module1.1 (GND), Module1.2 (GND), Module1.8 (GND), Module1.13 (GND), Module1.14 (GND), Module1.22 (GND), Module1.23 (GND), Module1.32 (GND), Module1.33 (GND), Module1.42 (GND), Module1.43 (GND), Module1.52 (GND), Module1.53 (GND), Module1.60 (GND), Module1.66 (GND), Module1.71 (GND), Module1.74 (GND), Module1.98 (GND), Module1.107 (GND), Module1.108 (GND), Module1.113 (GND), Module1.114 (GND), Module1.119 (GND), Module1.120 (GND), Module1.125 (GND), Module1.126 (GND), Module1.131 (GND), Module1.132 (GND), Module1.137 (GND), Module1.138 (GND), Module1.144 (GND), Module1.150 (GND), Module1.155 (GND), Module1.156 (GND), Module1.161 (GND), Module1.162 (GND), Module1.167 (GND), Module1.168 (GND), Module1.173 (GND), Module1.174 (GND), Module1.179 (GND), Module1.180 (GND), Module1.185 (GND), Module1.186 (GND), Module1.191 (GND), Module1.192 (GND), Module1.197 (GND), Module1.198 (GND), Q3.3 (S), Q4.3 (S), Q4#2.3 (S), R3.1, R5.1, R7.2, R10.1, R12.1, R15.2, R16.2, R20.1, R20.2, TVS-PUSB1.2 (GND), U3.7 (IOVSS), U3.17 (AVSS), U3.28 (DVSS), U4.10 (ACDRV2), U4.11 (ACDRV1), U4.27 (GND), U5.2 (PGND3), U5.7 (PGND1), U5.26 (PGND2), U6.4 (OUT-), U7.2 (GND), U7.3 (FB), U8.7 (PGND), U9.1, U9.4, U9.10, ZD1.2
BAT+: C7.1, C8.1, R9.2, U4.22 (BAT), U4.23 (BAT__1), U6.3 (OUT+)
CAM-SWITCH: TP3.1 (A), U9.15
CAM_CK_N: Module1.127 (MIPI0_C_N), U9.8
CAM_CK_P: Module1.129 (MIPI0_C_P), U9.9
CAM_D0_N: Module1.115 (MIPI0_D0_N), U9.2
CAM_D0_P: Module1.117 (MIPI0_D0_P), U9.3
CAM_D1_N: Module1.121 (MIPI0_D1_N), U9.5
CAM_D1_P: Module1.123 (MIPI0_D1_P), U9.6
CAM_IO0: TP4.1 (A), U9.11
CC1: J1.A5 (CC1), Module1.94 (CC1)
CC2: J1.B5 (CC2), Module1.96 (CC2)
D+: J1.A6 (D1+), J1.B6 (D2+), Module1.163 (USB3-1-D_P), TVS-PUSB1.5 (D+), TVS-PUSB2.5 (D+), U4.6 (D+)
D-: J1.A7 (D1-), J1.B7 (D2-), Module1.165 (USB3-1-D_N), TVS-PUSB1.4 (D-), TVS-PUSB2.4 (D-), U4.7 (D-)
DSI1_C_N: DIS1.11, Module1.187 (MIPI1_C_N)
DSI1_C_P: DIS1.12, Module1.189 (MIPI1_C_P)
DSI1_D0_N: DIS1.5, Module1.175 (MIPI1_D0_N)
DSI1_D0_P: DIS1.6, Module1.177 (MIPI1_D0_P)
DSI1_D1_N: DIS1.8, Module1.181 (MIPI1_D1_N)
DSI1_D1_P: DIS1.9, Module1.183 (MIPI1_D1_P)
DSI1_D2_N: DIS1.14, Module1.133 (MIPI0_D2_N), Module1.193 (MIPI1_D2_N)
DSI1_D2_P: DIS1.15, Module1.135 (MIPI0_D2_P), Module1.195 (MIPI1_D2_P)
EN3V3A-SW-OUT: SW1.2, U5.20 (EN_DCDC1)
GND: TVS-PUSB2.2 (GND), ZD2.2
GPIO2: Module1.58 (GPIO2), SW7.2
GPIO3: Module1.56 (GPIO3), SW6.2
GPIO4: Module1.54 (GPIO4), SW5.2
GPIO17: Module1.50 (GPIO17), SW4.2
GPIO22: Module1.46 (GPIO22), R25.1
GPIO27: Module1.48 (GPIO27), R24.1
LCD_PWM: Module1.55 (GPIO14), U7.4 (CTRL)
MIC-SWITCH: C5.2, C6.1, MK1.5 (VDD)
unnamed: C40.2, R23.1
unnamed: D1.2 (A), L5.2, U7.1 (SW)
unnamed: J3.8, R2.2
unnamed: LED1.2 (A), R17.1
unnamed: LED1.1 (K), R14.1, U4.1 (STAT)
unnamed: C1.1, Module1.157 (USB3-1-RX_N)
unnamed: C2.1, Module1.159 (USB3-1-RX_P)
unnamed: C3.1, Module1.169 (USB3-1-TX_N)
unnamed: C4.1, Module1.171 (USB3-1-TX_P)
unnamed: Q2.1 (G), SW3.2
unnamed: B1.N, D2.2, Q3.2 (D)
unnamed: Q3.1 (G), R24.2
unnamed: Q4.2 (D), Q4#2.2 (D), U10.1 (-), U10#2.1 (-)
unnamed: Q4.1 (G), Q4#2.1 (G), R25.2
unnamed: R9.1, U4.18 (BATP)
unnamed: C15.2, U4.4 (BTST1)
unnamed: C16.2, U4.19 (BTST2)
unnamed: R4.1, R7.1, U4.17 (ILIM_HIZ)
unnamed: C11.1, C12.1, C13.1, C14.1, U4.29 (PMID)
unnamed: R5.2, U4.20 (PROG)
unnamed: C9.1, U4.24 (SDRV)
unnamed: C15.1, L1.2, U4.28 (SW1)
unnamed: C16.1, L1.1, U4.26 (SW2)
unnamed: R13.2, R15.1, R16.1, U4.16 (TS)
unnamed: R6.2, R10.2, U5.32 (DEFDCDC3)
unnamed: L2.2, U5.6 (L1)
unnamed: L3.2, U5.27 (L2)
unnamed: L4.2, U5.3 (L3)
unnamed: R11.1, R12.2, U5.30 (PWRFAIL_SNS)
unnamed: C32.1, U8.13 (BST)
unnamed: C40.1, U8.4 (COMP)
unnamed: R21.2, R22.1, U8.5 (FB)
unnamed: C42.1, U8.3 (SS)
unnamed: C32.2, L6.2, U8.1 (SW)
unnamed: C41.2, U8.2 (VDD)
REGN: C10.1, R4.2, R13.1, R17.2, U4.5 (REGN)
RX1+: C2.2, J1.A11 (RX2+), J1.B11 (RX1+), TVS-PUSB1.7 (RX+), TVS-PUSB2.7 (RX+)
RX1-: C1.2, J1.A10 (RX2-), J1.B10 (RX1-), TVS-PUSB1.6 (Rx-), TVS-PUSB2.6 (Rx-)
SPI0_CLK: J3.2, Module1.38 (GPIO11)
SPI0_CS: J3.5, Module1.39 (GPIO8)
SPI0_MISO: J3.3, Module1.40 (GPIO9)
SPI0_MOSI: J3.4, Module1.44 (GPIO10)
SPI0_RDY: J3.6, Module1.34 (GPIO5)
SYS: C17.1, C18.1, C19.1, C20.1, C21.1, C22.1, C23.1, C24.1, C25.1, C26.1, C31.1, C33.1, C34.1, C35.1, L5.1, L6.1, R11.2, U4.25 (SYS), U5.4 (VINDCDC3), U5.5 (VINDCDC1), U5.9 (DEFDCDC1), U5.28 (VINDCDC2), U5.29 (VCC), U7.6 (VIN), U8.10 (MODE), U8.11 (EN), U8.12 (VIN)
TX1+: C4.2, J1.A2 (TX1+), J1.B2 (TX2+), TVS-PUSB1.3 (Tx+), TVS-PUSB2.3 (Tx+)
TX1-: C3.2, J1.A3 (TX1-), J1.B3 (TX2-), TVS-PUSB1.1 (Tx-), TVS-PUSB2.1 (Tx-)
USBC POW: J1.A4 (VBUS_A), J1.A9 (VBUS_A__1), J1.B4 (VBUS_B), J1.B9 (VBUS_B__1), U4.2 (VBUS), U4.8 (VAC2), U4.9 (VAC1), ZD1.1, ZD2.1
VCC: B1.P, D2.1, J3.7, J3.10, R2.1, R14.2, R18.1, SW4.1, SW5.1, SW6.1, SW7.1, U3.24 (AVDD), U10.2 (+), U10#2.2 (+)
~INT: R18.2, U4.21 (~INT)
~PWRFAIL: R8.2, U5.21 (~PWRFAIL)

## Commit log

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2024-12-01 switch to kicad 8
    [cm4-carrier.csv, cm4-carrier.kicad_pcb, cm4-carrier.kicad_sch]
2025-01-05 finish USB C 32
    [TVS-array-PUSB3FR6Z.step, USB-ESD-protection-diode-PESD5V0C1USFYL-SOD962-2_DSN0603-2_NEX.step, USBC_capacitor_GRM033R60J334ME90D.step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]
2025-01-05 finish USB C kicad 8
    [cm4-carrier.kicad_pcb, cm4-carrier.kicad_sch]
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2025-07-01 fix USB C EDA files & add usb c pinout to schematic
    [USBC-3-2-fix-USB4056-03-A_REVA2.step, cm5-carrier.kicad_pcb, cm5-carrier.kicad_sch]
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2025-07-02 add cutout for battery
    [cm5-carrier.kicad_pcb, cm5-carrier.kicad_sch]
2025-07-03 increase cutout to 51.5 x 78.5
    [cm5-carrier.kicad_pcb]
2025-07-03 New battery, its now a 3500mah one
    [cm5-carrier.kicad_pcb, cm5-carrier.kicad_sch]
2025-07-04 remove levitating bat leads
    [cm5-carrier.kicad_pcb]
2025-07-15 flashlight and vibration MOSFET drivers
    [1K-05W-0805-RES_ERJP06J102V.step, cm5-carrier.kicad_pcb, cm5-carrier.kicad_sch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]
2025-07-15 assign new 3500 mAh bat footprint to symbol
    [cm5-carrier.kicad_pcb, cm5-carrier.kicad_sch]
2025-07-25 split schematic into multiple files
    [GSM-GPS.kicad_sch, USB-C.kicad_sch, audio.kicad_sc.kicad_sch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]
2025-07-25 Power system is finally working, i hope so atleast. Issues are the syme as gefore (2 resistors missing values and a missing BATFET connection, but everything is marked so it should be easy to find
    [cm5-carrier.kicad_pcb, power.kicad_sch]
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2025-08-09 fix'ed 3D models
    [cm5-carrier.kicad_pcb]
2025-08-09 fixed paths
    there where a bit wrong last time
    [cm5-carrier.kicad_pcb]
2025-08-09 more paths fixed
    [cm5-carrier.kicad_pcb]
2025-08-09 thermistor fixed
    [cm5-carrier.kicad_pcb]
2025-08-09 cm module fixed
    [cm5-carrier.kicad_pcb]
2025-08-09 headphone jack moved flush with board edge
    and mounted from the other side to save height
    [cm5-carrier.kicad_pcb]
2025-08-10 added brick models for battery and fingerprint scanner
    [cm5-carrier.kicad_pcb]
2025-08-10 last button now flush with board edge
    [cm5-carrier.kicad_pcb]
2025-08-10 moved off board components near what they control
    [cm5-carrier.kicad_pcb]
2025-08-10 added 3d model for flashlight
    [Flash-LED-Lumiled.stp, cm5-carrier.kicad_pcb]
2025-08-10 finger print scanner model added
    we still need to board connector
    [cm5-carrier.kicad_pcb, finger print scanner module.stp]
2025-08-10 enabled the top speaker
    forgot that i had set it to hidden
    [cm5-carrier.kicad_pcb]
2025-08-10 better (i think) cm5 model
    [cm5-carrier.kicad_pcb]
2025-08-10 finger print scanner connected
    missing pin 6 and 7, and we still need a 3d model of the connector for the board
    link to datasheet: https://mm.digikey.com/Volume0/opasdata/d220001/medias/docus/5676/SPC26627-3_BM-LITE_Safetouch_Spec.pdf
    [cm5-carrier.kicad_sch, fingerprint.kicad_sch]
2025-08-12 fixed audio jack and usb placement
    [cm5-carrier.kicad_pcb]
2025-08-12 #10 Added Battery 3D Model (STEP)
    [Battery_lp685077jupcm2.step]
2025-08-12 schematic cleaned up a bit
    [USB-C.kicad_sch, cm5-carrier.kicad_pcb, fingerprint.kicad_sch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]
2025-08-13 fix's as per discord caht
    [cm5-carrier.kicad_pcb, cm5-carrier.kicad_sch]
2025-08-13 and here is fingerprint sch
    [fingerprint.kicad_sch]
2025-08-13 link new battery model to footprint
    [USB-C.kicad_sch, cm5-carrier.kicad_pcb, cm5-carrier.kicad_sch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]
2025-08-13 fully sync pcb to schematic, fix some models
    [USB-C.kicad_sch, cm5-carrier.kicad_pcb, cm5-carrier.kicad_sch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]
2025-08-13 add fingerprint scanner FPC connector model
    [10-FPC-unused.stp, cm5-carrier.kicad_pcb, molex-10pin-fingerprint-scanner-connector-5034801000.stp]
2025-08-13 remove SBU test pads from USB C
    [USB-C.kicad_sch, cm5-carrier.kicad_pcb, cm5-carrier.kicad_sch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]
2025-08-14 3d model of figner scanner re-enabled
    someone (prob me) turned it off and did not enable it again
    [cm5-carrier.kicad_pcb]
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2025-08-14 footprints assigned to all resistors
    [power.kicad_sch]
2025-08-14 added footprints to transistors
    used the footprint assigned to Q1
    check my work
    [flashlight.kicad_sch, power.kicad_sch]
2025-08-14 added footprint for diodes
    and also added the pcb update report
    [power.kicad_sch]
2025-08-14 updated the pcb
    we still have errors and we need to check the correct footprints are selected for each component
    [cm5-carrier.kicad_pcb]
2025-08-14 Revert "updated the pcb"
    This reverts commit b83bfcf242b39ab1cc39cb22d321c5bb6567aa93.
    [cm5-carrier.kicad_pcb]
2025-08-14 update pcb
    trying again
    [cm5-carrier.kicad_pcb]
2025-08-14 center USBC, mount speakers simmmetricallly
    [cm5-carrier.kicad_pcb]
2025-08-14 remove CM5 drill hole avoiding EC25 conflict
    [cm5-carrier.kicad_pcb]
2025-08-14 fix power button clearance issue
    [cm5-carrier.kicad_pcb]
2025-08-14 add symmetry lines to layout
    [cm5-carrier.kicad_pcb]
2025-08-14 added step files for the touchscreen (RK055AHD091-CTG)
    [display-RK055AHD091-CTG-ribbon-straight.step, display-RK055AHD091-CTG-ribbon-tucked.step]
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2025-08-14 fix camera mount point
    [16MP-Autofocus.STEP, cm5-carrier.kicad_pcb]
2025-08-14 finish fingerprint sensor placement
    [cm5-carrier.kicad_pcb]
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2025-08-14 add cutout for fingerprint sensor cable
    [cm5-carrier.kicad_pcb]
2025-08-15 add corner drill holes
    [cm5-carrier.kicad_pcb]
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2025-08-20 add EG25 new gpsgsm
    [EG25GGC-128-SGNS.step, GSM-GPS.kicad_sch, USB-C.kicad_sch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]
2025-08-20 new component layout to fix cm5 heat issue
    [cm5-carrier.kicad_pcb]
2025-08-21 fix hole sizes
    [cm5-carrier.kicad_pcb]
2025-08-21 upgrade usb c to waterproof and 4-0
    [GSM-GPS.kicad_sch, USB-4-0-CX90MW9-24P1.step, USB-C.kicad_sch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]
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2025-08-22 fix buttons 2
    [cm5-carrier.kicad_pcb]
2025-08-23 add clearance
    [USB-C.kicad_sch, audio.kicad_sc.kicad_sch, cm5-carrier.kicad_pcb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]
2025-08-24 connect codec clocks to GPIO and specify alt functions
    [USB-C.kicad_sch, audio.kicad_sc.kicad_sch, cm5-carrier.kicad_sch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]
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2025-09-01 Completely wired up power section. Ill do the cm5 5v rail in a latercommit, just so this commit isnt growing too large. I put lots of work and thought in making it easy to work with, so i hope you li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
    [power.kicad_sch]
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2025-09-02 Added the usb pow back and added the 5v @ 5a rail
    [power.kicad_sch]
2025-09-04 fix STAT pin LED, connect USB POW, remove d3
    [0603-resistor.step, USB-C.kicad_sch, cm5-carrier.kicad_sch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]
2025-09-05 add BSC0902NSI power section transistor
    [BSC0902NSIATMA1-PG-TDSON-8-6.step]
2025-09-08 connect charger IC pins 1 though 15
    [USB-C.kicad_sch, cm5-carrier.kicad_sch, fingerprint.kicad_sch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]
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2025-09-09 exclude old EC25 and minor changes to power
    [GSM-GPS.kicad_sch, USB-C.kicad_sch, cm5-carrier.kicad_sch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]
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2025-09-12 add step, footprint and better symbol for 5V 5A rail
    [MP3429GL.step, power.kicad_sch]
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2025-09-18 TPS650250 3V3 and 1V8 rails connected, PWRFAIL threshold set
    [power.kicad_sch]
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2025-09-22 separate regulator EN labels for fine grained power saving features etc
    [cm5-carrier.kicad_sch, power.kicad_sch]
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2025-09-22 add placeholder symbols to 22V rail zener and r3
    [power.kicad_sch]
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2025-09-28 fix import schematic to pcb errors
    [cm5-carrier.kicad_pcb, power.kicad_sch]
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2025-09-30 improve and fix footprints, add mini silkscreen symbols
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2025-09-30 assign power section footprints and import to pcb
    [USB-C.kicad_sch, audio.kicad_sc.kicad_sch, cm5-carrier.kicad_pcb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]
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2025-10-02 add correct charger footprint and step file
    [charger-BQ25792RQMR.step]
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2025-11-30 FIxed PCB length as per TheTicraft (MavLeague) request
    [cm5-carrier.kicad_pcb]
2026-01-24 removed symbol and footprint for TPS650250 and replaced that PMIC TPS65023
    [TPS65023BRSBR.stp, TPS650250RHBR.step, power.kicad_sch]
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2026-01-29 Fixed PCB outline and removed duplicate library "MP3429"
    [cm5-carrier.kicad_pcb]
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2026-02-09 fix fuse placement
    [power.kicad_sch]
2026-02-09 Added 1210-1812 universal size footprint for resettable fuse.
    [power.kicad_sch]
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2026-02-10 connect VBACKUP to GND since no backup battery
    [power.kicad_sch]
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2026-02-10 distinguish between BQ INT and TPS INT pins
    [cm5-carrier.kicad_sch, power.kicad_sch]
2026-02-10 Revert "Merge branch 'main' of https://github.com/Engineer162/SPIRIT"
    This reverts commit 4b9d5e5eeadd9fbbdfcd67c9cf1a6d4bc6ec3008, reversing
    changes made to 5bc2bb510634a0db9cf47dc57074958cd1daf157.
    [cm5-carrier.kicad_sch, power.kicad_sch]
2026-02-10 Reapply "Merge branch 'main' of https://github.com/Engineer162/SPIRIT"
    This reverts commit faadb4b06c766ed7acf40c481909d61e62fd8808.
    [cm5-carrier.kicad_sch, power.kicad_sch]
2026-02-10 Fixed Git having a meltdown
    Please send help git nuked my fork and i painfully reverted the stuff that got blown up. Also a 3D model's name made git go crazy so that was changed as well (the 3D model was UBAF30-D2011´+ê3D´+ë.STEP name has been changed to UBAF30-D2011+3D+.STEP to stop git from ever going crazy again)
    [power.kicad_sch]
2026-02-10 Fixed 3D model files having non ASCII file name characters and spaces
    [TRJG0926HENL .stp, TRJG0926HENL.stp]
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2026-02-25 swap VRTC cap
    [power.kicad_sch]
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2026-02-27 applied no backup bat config to VSYSIN, removed standby label
    [power.kicad_sch]
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2026-03-03 fix wrong capacitors on DCDC output
    [power.kicad_sch]
2026-03-03 Add MPN to 0 Ohm jumper symbols, shorten text
    [power.kicad_sch]
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

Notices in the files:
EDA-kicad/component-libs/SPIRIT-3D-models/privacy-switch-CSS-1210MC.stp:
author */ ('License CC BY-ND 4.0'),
